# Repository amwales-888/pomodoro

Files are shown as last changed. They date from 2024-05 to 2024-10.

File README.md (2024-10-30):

# Pomodoro Timer

This simple project was requested by a client.

### Step 1. Hardware time preset

Produce a Pomodoro Timer where you can set the working time and rest time

The client proposed a set of jumper headers to configure timers along with a sketch of the hardware.

<table>
  <tr>
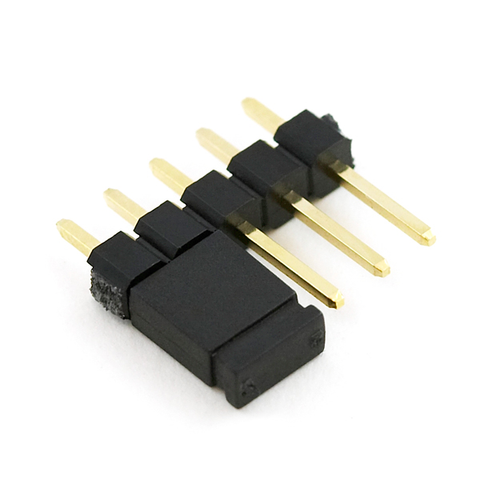
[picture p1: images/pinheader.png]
    <td> </td>
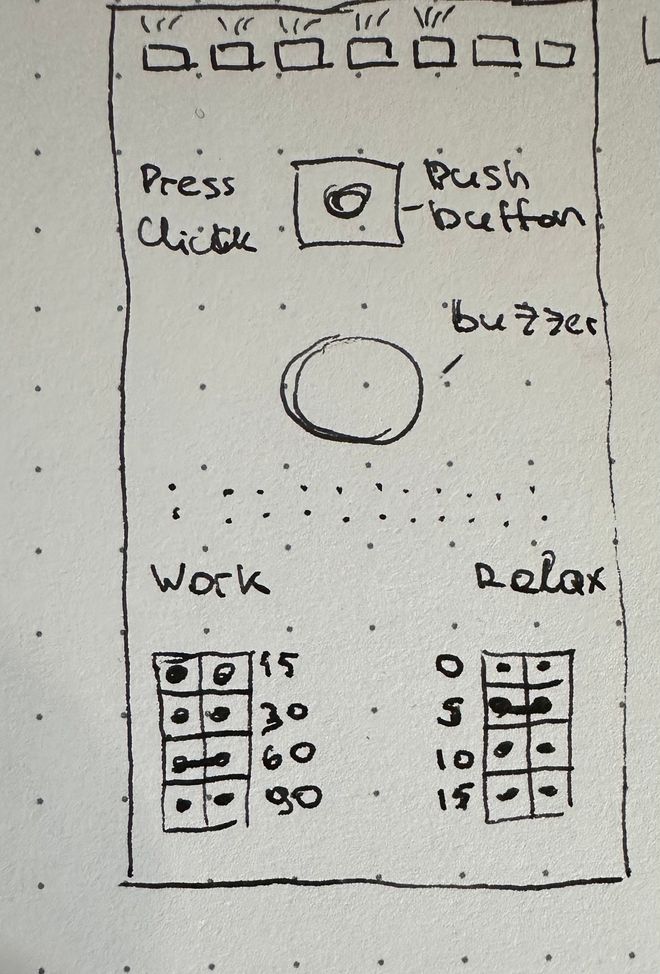
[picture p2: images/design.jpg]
    <td> </td>
  </tr>
</table>

Timers value are hardcoded 

Working time

- 15 minutes
- 30 minutes
- 60 minutes
- 90 minutes

Relax time

-  0 min
-  5 min
- 10 min
- 15 min

A row of LED are used to display the state of the timers.

### Step 2. Start timer

User clicks button to start timer

User hears sound from buzzer

LED progress bar turned on 

- Logic of the LED progress bar
    - Countdown progress bar
        - Ex: 30 minutes timer
        - 10 LEDs are on
        - the last one 10th is flashing
        - Every 3 minutes (time/amount of leds) 1 led turn off, after 3 minutes only 9 are on, the 9th is flashing

### Step 3. Timer is over

Once working timer is over:

- All progress bar LEDs flash
- Buzzer produce sound

Then User click button and Relax(Rest) timer began with the same logic

- Led progress bar has different color
- Once Rest timer finished - another melody is playing

To stop timer the User must hold the button pressed for 3 seconds. 

No pause function needed

### Power requirements

Ideally make it run from a tiny battery like CR2032 or 2-3 AAA Batteries.

### Enclosure requirements

No enclosure or enclosure built from PCB

### Size requirements

Less than 85 mm x 50mm 

## Proposal

 - Use a lowcost <a href="Firmware/pic16f15355/docs/PIC16F-LF-15354-55-Data-Sheet-DS40001853.pdf">pic16lf15355</a> SOIC 28 MCU which can be powered from 1.8v-5v, running from internal oscillator and able to idle at very low current.
 - Use 7 red/green bi-color, low power LEDs 
 - Use 2 AAA Batteries in series at 2v-3v to extend runtime and reduce end user cost over lithium CR2032 cell.
 - Use Microchip MPLAB-X, XC8 and Pickit5 for development.
 - 67mm x 40mm board area, battery holder mounted on the back.

<table>
  <tr>
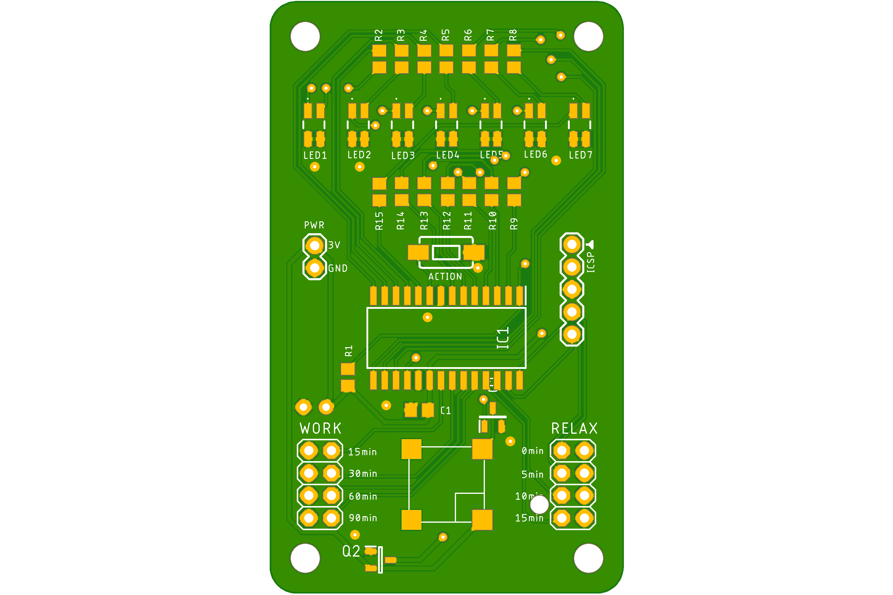
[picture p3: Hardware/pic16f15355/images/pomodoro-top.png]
    <td> </td>
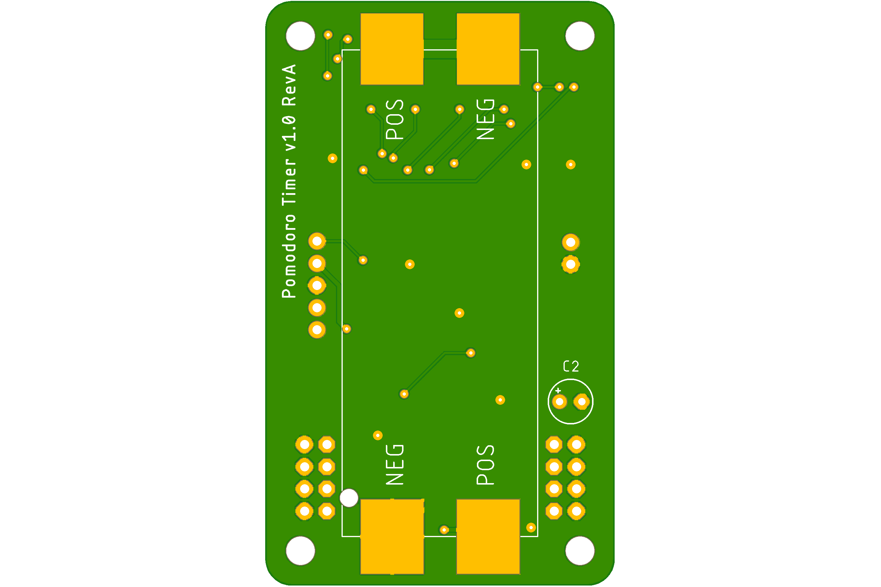
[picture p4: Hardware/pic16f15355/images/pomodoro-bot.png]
    <td> </td>
  </tr>
</table>

## Completed Project 

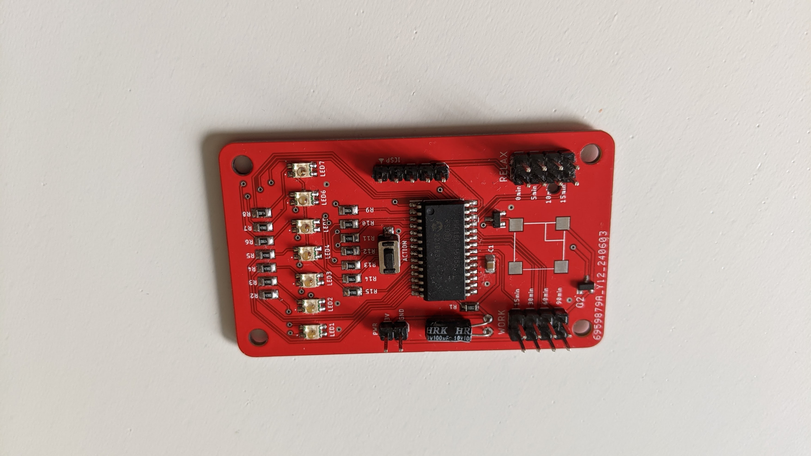
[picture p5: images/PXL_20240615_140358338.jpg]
Working, partially populated board 

## Project revision

I recently started investigating the py32 series of microcontrollers from puya, these are very low cost ( 12cents, you read that correctly ) arm-cortex-m0 processors running at 24MHz.
I ported the pomodoro firmware for the pic16 targeting the py32 controller and redsigned the board to support a tssop20 package. The new hardware is aimed at owering costs, along with the processor selection I opted for 14 leds in 0603 packages to reduce the cost. The complete BOM comes in at less than $1 and has feature parity with the original, supporting the same number of output and inputs as the original.

<table>
  <tr>
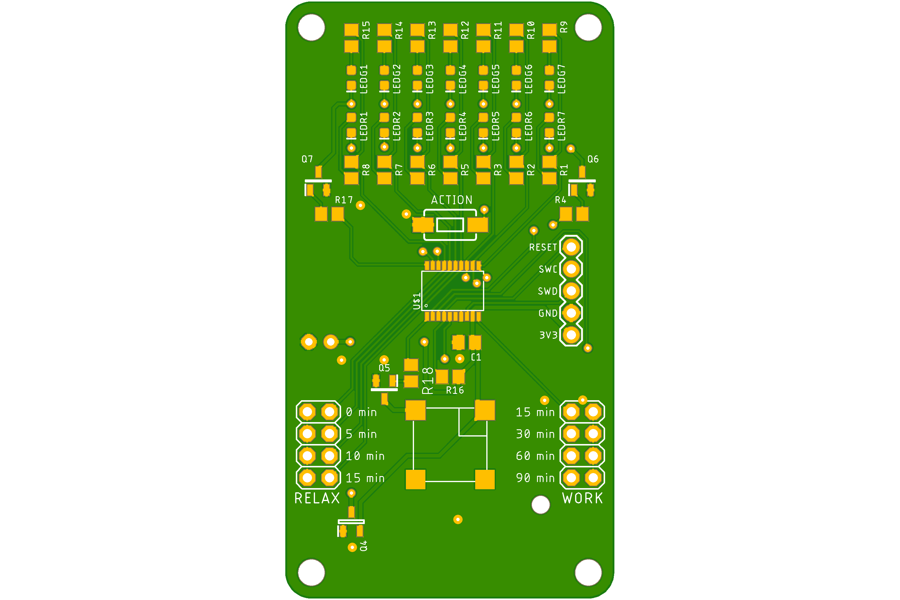
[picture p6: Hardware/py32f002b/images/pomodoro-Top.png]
    <td> </td>
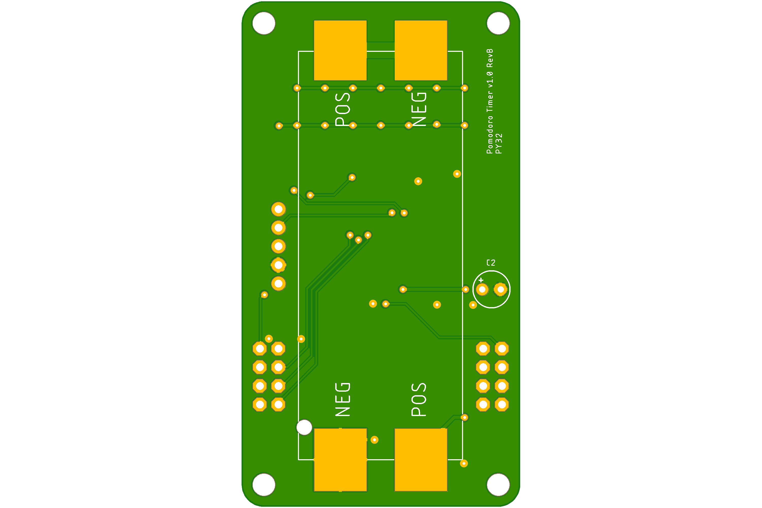
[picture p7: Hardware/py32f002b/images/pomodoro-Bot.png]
    <td> </td>
  </tr>
</table>

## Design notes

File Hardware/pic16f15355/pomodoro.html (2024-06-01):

Partlist exported from C:/Users/Angelo/Projects/pomodoro-pic16f15355/Hardware/pomodoro-pic16f15355/pomodoro.sch at 01/06/2024 14:47

Part | Value | Device | Package | Description | DESCRIPTION | HEIGHT | MANUFACTURER_NAME | MANUFACTURER_PART_NUMBER | MOUSER_PART_NUMBER | MOUSER_PRICE-STOCK | POPULARITY | PROD_ID | SF_SKU | SPICEPREFIX
ACTION | MOMENTARY-SWITCH-SPST-SMD-6.0X3.5MM | MOMENTARY-SWITCH-SPST-SMD-6.0X3.5MM | TACTILE_SWITCH_SMD_6.0X3.5MM | Momentary Switch (Pushbutton) - SPST | | | | | | | | SWCH-14278 | COM-08229
C1 | 0.1uf | C-EUC0805 | C0805 | CAPACITOR, European symbol | | | | | | | 88 | | | C
C2 | | CPOL-EUE2.5-5 | E2,5-5 | POLARIZED CAPACITOR, European symbol | | | | | | | 16 | | | C
IC1 | PIC16F15355T-I_SO | PIC16F15355T-I_SO | SOIC127P1030X265-28M | MCU 8-bit PIC RISC 14KB Flash 3.3V/5V 28-Pin SOIC W T/R | MCU 8-bit PIC RISC 14KB Flash 3.3V/5V 28-Pin SOIC W T/R | 2.65mm | Microchip | PIC16F15355T-I/SO | 579-PIC16F15355TI/SO | https://www.mouser.co.uk/ProductDetail/Microchip-Technology/PIC16F15355T-I-SO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
ICSP | | CONN_05 | 1X05 | Multi connection point. Often used as Generic Header-pin footprint for 0.1 inch spaced/style header connections
LED1 | APBD3224LSURKCGKC | APBD3224LSURKCGKC | APBD3224LSURKCGKC | Standard LEDs - SMD 3.2x2.4MM LOW CU RED/GREEN SMD | Standard LEDs - SMD 3.2x2.4MM LOW CU RED/GREEN SMD | 2.4mm | Kingbright | APBD3224LSURKCGKC | 604-APBD3224LSURKCGK | https://www.mouser.co.uk/ProductDetail/Kingbright/APBD3224LSURKCGKC?qs=ZqXcJfGlKsjckDFm0SXANw%3D%3D
LED2 | APBD3224LSURKCGKC | APBD3224LSURKCGKC | APBD3224LSURKCGKC | Standard LEDs - SMD 3.2x2.4MM LOW CU RED/GREEN SMD | Standard LEDs - SMD 3.2x2.4MM LOW CU RED/GREEN SMD | 2.4mm | Kingbright | APBD3224LSURKCGKC | 604-APBD3224LSURKCGK | https://www.mouser.co.uk/ProductDetail/Kingbright/APBD3224LSURKCGKC?qs=ZqXcJfGlKsjckDFm0SXANw%3D%3D
LED3 | APBD3224LSURKCGKC | APBD3224LSURKCGKC | APBD3224LSURKCGKC | Standard LEDs - SMD 3.2x2.4MM LOW CU RED/GREEN SMD | Standard LEDs - SMD 3.2x2.4MM LOW CU RED/GREEN SMD | 2.4mm | Kingbright | APBD3224LSURKCGKC | 604-APBD3224LSURKCGK | https://www.mouser.co.uk/ProductDetail/Kingbright/APBD3224LSURKCGKC?qs=ZqXcJfGlKsjckDFm0SXANw%3D%3D
LED4 | APBD3224LSURKCGKC | APBD3224LSURKCGKC | APBD3224LSURKCGKC | Standard LEDs - SMD 3.2x2.4MM LOW CU RED/GREEN SMD | Standard LEDs - SMD 3.2x2.4MM LOW CU RED/GREEN SMD | 2.4mm | Kingbright | APBD3224LSURKCGKC | 604-APBD3224LSURKCGK | https://www.mouser.co.uk/ProductDetail/Kingbright/APBD3224LSURKCGKC?qs=ZqXcJfGlKsjckDFm0SXANw%3D%3D
LED5 | APBD3224LSURKCGKC | APBD3224LSURKCGKC | APBD3224LSURKCGKC | Standard LEDs - SMD 3.2x2.4MM LOW CU RED/GREEN SMD | Standard LEDs - SMD 3.2x2.4MM LOW CU RED/GREEN SMD | 2.4mm | Kingbright | APBD3224LSURKCGKC | 604-APBD3224LSURKCGK | https://www.mouser.co.uk/ProductDetail/Kingbright/APBD3224LSURKCGKC?qs=ZqXcJfGlKsjckDFm0SXANw%3D%3D
LED6 | APBD3224LSURKCGKC | APBD3224LSURKCGKC | APBD3224LSURKCGKC | Standard LEDs - SMD 3.2x2.4MM LOW CU RED/GREEN SMD | Standard LEDs - SMD 3.2x2.4MM LOW CU RED/GREEN SMD | 2.4mm | Kingbright | APBD3224LSURKCGKC | 604-APBD3224LSURKCGK | https://www.mouser.co.uk/ProductDetail/Kingbright/APBD3224LSURKCGKC?qs=ZqXcJfGlKsjckDFm0SXANw%3D%3D
LED7 | APBD3224LSURKCGKC | APBD3224LSURKCGKC | APBD3224LSURKCGKC | Standard LEDs - SMD 3.2x2.4MM LOW CU RED/GREEN SMD | Standard LEDs - SMD 3.2x2.4MM LOW CU RED/GREEN SMD | 2.4mm | Kingbright | APBD3224LSURKCGKC | 604-APBD3224LSURKCGK | https://www.mouser.co.uk/ProductDetail/Kingbright/APBD3224LSURKCGKC?qs=ZqXcJfGlKsjckDFm0SXANw%3D%3D
PWR | | CONN_02 | 1X02 | Multi connection point. Often used as Generic Header-pin footprint for 0.1 inch spaced/style header connections
Q1 | IRLML2502TRPBF | IRLML2502TRPBF | SOT95P237X112-3N | IRLML2502TRPBF N-Channel MOSFET, 4.2 A, 20 V IRLML2502, 3-Pin SOT-23 Infineon | IRLML2502TRPBF N-Channel MOSFET, 4.2 A, 20 V IRLML2502, 3-Pin SOT-23 Infineon | 1.12mm | Infineon | IRLML2502TRPBF | 942-IRLML2502TRPBF | https://www.mouser.co.uk/ProductDetail/Infineon-Technologies/IRLML2502TRPBF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
Q2 | DMG2305UX-7 | DMG2305UX-7 | SOT96P240X115-3N | MOSFET P-Ch 20V 5A Enhancement SOT23 Diodes Inc DMG2305UX-7 P-channel MOSFET Transistor, -3.3 A, -20 V, 3-Pin SOT-23 | MOSFET P-Ch 20V 5A Enhancement SOT23 Diodes Inc DMG2305UX-7 P-channel MOSFET Transistor, -3.3 A, -20 V, 3-Pin SOT-23 | 1.15mm | Diodes Incorporated | DMG2305UX-7 | 621-DMG2305UX-7 | https://www.mouser.co.uk/ProductDetail/Diodes-Incorporated/DMG2305UX-7?qs=L1DZKBg7t5F%2FNBHrjfxC%252Bg%3D%3D
R1 | 10K | R-EU_R0805 | R0805 | RESISTOR, European symbol | | | | | | | 86 | | | R
R2 | 330R | R-EU_R0805 | R0805 | RESISTOR, European symbol | | | | | | | 86 | | | R
R3 | 330R | R-EU_R0805 | R0805 | RESISTOR, European symbol | | | | | | | 86 | | | R
R4 | 330R | R-EU_R0805 | R0805 | RESISTOR, European symbol | | | | | | | 86 | | | R
R5 | 330R | R-EU_R0805 | R0805 | RESISTOR, European symbol | | | | | | | 86 | | | R
R6 | 330R | R-EU_R0805 | R0805 | RESISTOR, European symbol | | | | | | | 86 | | | R
R7 | 330R | R-EU_R0805 | R0805 | RESISTOR, European symbol | | | | | | | 86 | | | R
R8 | 330R | R-EU_R0805 | R0805 | RESISTOR, European symbol | | | | | | | 86 | | | R
R9 | 330R | R-EU_R0805 | R0805 | RESISTOR, European symbol | | | | | | | 86 | | | R
R10 | 330R | R-EU_R0805 | R0805 | RESISTOR, European symbol | | | | | | | 86 | | | R
R11 | 330R | R-EU_R0805 | R0805 | RESISTOR, European symbol | | | | | | | 86 | | | R
R12 | 330R | R-EU_R0805 | R0805 | RESISTOR, European symbol | | | | | | | 86 | | | R
R13 | 330R | R-EU_R0805 | R0805 | RESISTOR, European symbol | | | | | | | 86 | | | R
R14 | 330R | R-EU_R0805 | R0805 | RESISTOR, European symbol | | | | | | | 86 | | | R
R15 | 330R | R-EU_R0805 | R0805 | RESISTOR, European symbol | | | | | | | 86 | | | R
RELAX | | PINHD-2X4 | 2X04 | PIN HEADER | | | | | | | 47
U$1 | 2AAABATT | 2AAABATT | 2AAABATTSER
U$2 | BUZZER8X8 | BUZZER8X8 | BUZZER8X8
WORK | | PINHD-2X4 | 2X04 | PIN HEADER | | | | | | | 47

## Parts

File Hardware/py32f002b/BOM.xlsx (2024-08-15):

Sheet: Sheet1
LCSC Part Number | Manufacture Part Number | Manufacturer | Customer NO. | Package | Description |  | Unit Price($) | #Required | Price
C7496820 | F.0603.00139/P2-0603R1TS2-06T-002 | TUOZHAN |  | 603 | 5mA -40â„ƒ~+85â„ƒ Red 120Â° 0603 LED Indication - Discrete ROHS |  | 0.0031 | 7 | 0.0217
C7496818 | F.0603.00025/P2-0603G1TS2-06T-002 | TUOZHAN |  | 603 | 5mA 230mcd 520nm~525nm -40â„ƒ~+85â„ƒ Emerald 120Â° 2.6V~2.9V 0603 LED Indication - Discrete ROHS |  | 0.0029 | 7 | 0.0203
C94599 | MLT-8530 | Jiangsu Huaneng Elec |  | SMD,8.5x8.5mm | 80dB Externally Driven Magnetic 2.7kHz SMD,8.5x8.5mm Buzzers ROHS |  | 0.1924 | 1 | 0.1924
C22438998 | PY32F002BF15P6TR | PUYAï¼‰ |  | TSSOP-20 | TSSOP-20 Microcontrollers (MCU/MPU/SOC) ROHS |  | 0.1369 | 1 | 0.1369
C5290190 | BH-AAA-B1AJ015-60 | MYOUNG |  | - | Battery case No 7 - Button And Strip Battery Connector ROHS |  | 0.2714 | 1 | 0.2714
C429959 | 12251140CNG0S115001 | JILN |  | Plugin,P=2.54mm | 3A Straight Square Pins 2.5mm 40P 6mm -40â„ƒ~+105â„ƒ 3mm 2.54mm Plugin Black Brass 1x40P Plugin,P=2.54mm Pin Headers ROHS |  | 0.1016 | 1 | 0.1016
C17471 | 0805W8F1500T5E | UNI-ROYAL(Uniroyal Elec) |  | 805 | 125mW Thick Film Resistors 150V Â±100ppm/â„ƒ Â±1% 150Î© 0805 Chip Resistor - Surface Mount ROHS |  | 0.0017 | 14 | 0.0238
C150470 | DMG2305UX-7 | Diodes Incorporated |  | SOT-23 | 20V 4.2A 52mÎ©@4.5V,4.2A 1.4W 900mV@250uA 1PCSPChannel SOT-23 MOSFETs ROHS |  | 0.0466 | 1 | 0.0466
C337069 | SL3906 | Slkor(SLKORMICRO Elec.) |  | SOT-23 | 40V 225mW 100@10mA,1V 200mA PNP SOT-23 Bipolar (BJT) ROHS |  | 0.0075 | 3 | 0.0225
C66501 | CL10B104KO8NNNC | Samsung Electro-Mechanics |  | 603 | 16V 100nF X7R Â±10% 0603 Multilayer Ceramic Capacitors MLCC - SMD/SMT ROHS |  | 0.0026 | 1 | 0.0026
C84376 | RC0805FR-0710KL | YAGEO |  | 805 | 125mW Thick Film Resistors 150V Â±100ppm/â„ƒ Â±1% 10kÎ© 0805 Chip Resistor - Surface Mount ROHS |  | 0.0019 | 1 | 0.0019
C7499926 | CD110107M1A0407VFL | HRK |  | Plugin,D4xL7mm | 100uF 10V Plugin,D4xL7mm Aluminum Electrolytic Capacitors - Leaded ROHS |  | 0.0056 | 1 | 0.0056
 |  |  |  |  |  |  |  |  | 0.8473
ACTION | MOMENTARY-SWITCH-SPST-SMD-6.0X3.5MM | MOMENTARY-SWITCH-SPST-SMD-6.0X3.5MM
C1 | 100nf | C-EUC0805 |  | CAPACITOR, European symbol
C2 | 100uf | CPOL-EUE2.5-5 |  | POLARIZED CAPACITOR, European symbol
J1 |  | CONN_05 |  | PIN HEADER
LEDG1 | 20ma | LEDSML0805 |  | LED |  | 0.0031
LEDG2 | 20ma | LEDSML0805 |  | LED |  | 0.0031
LEDG3 | 20ma | LEDSML0805 |  | LED |  | 0.0031
LEDG4 | 20ma | LEDSML0805 |  | LED |  | 0.0031
LEDG5 | 20ma | LEDSML0805 |  | LED |  | 0.0031
LEDG6 | 20ma | LEDSML0805 |  | LED |  | 0.0031
LEDG7 | 20ma | LEDSML0805 |  | LED |  | 0.0031
LEDR1 | 20ma | LEDSML0805 |  | LED |  | 0.0031
LEDR2 | 20ma | LEDSML0805 |  | LED |  | 0.0031
LEDR3 | 20ma | LEDSML0805 |  | LED |  | 0.0031
LEDR4 | 20ma | LEDSML0805 |  | LED |  | 0.0031
LEDR5 | 20ma | LEDSML0805 |  | LED |  | 0.0031
LEDR6 | 20ma | LEDSML0805 | C7496820 | LED |  | 0.0031
LEDR7 | 20ma | LEDSML0805 | C7496818 | LED |  | 0.0031
Q4 | DMG2305UX-7 | DMG2305UX-7 | C150470 | MOSFET P-Ch 20V 5A Enhancement SOT23 Diodes Inc DMG2305UX-7 P-channel MOSFET Transistor, -3.3 A, -20 V, 3-Pin SOT-23 |  | 0.0466
Q5 | MMBT3904LT3G | MMBT3904LT3G | C337069 | Transistor NPN 40V 200mA SOT-23 ON Semi MMBT3904LT3G NPN Bipolar Transistor, 900 mA 40 V, 3-Pin SOT-23
Q6 | MMBT3904LT3G | MMBT3904LT3G | C337069 | Transistor NPN 40V 200mA SOT-23 ON Semi MMBT3904LT3G NPN Bipolar Transistor, 900 mA 40 V, 3-Pin SOT-23
Q7 | MMBT3904LT3G | MMBT3904LT3G | C337069 | Transistor NPN 40V 200mA SOT-23 ON Semi MMBT3904LT3G NPN Bipolar Transistor, 900 mA 40 V, 3-Pin SOT-23
R1 | 100R | R-EU_R0805 |  | RESISTOR, European symbol
R2 | 100R | R-EU_R0805 |  | RESISTOR, European symbol
R3 | 100R | R-EU_R0805 |  | RESISTOR, European symbol
R4 | 10k | R-EU_R0805 |  | RESISTOR, European symbol
R5 | 100R | R-EU_R0805 |  | RESISTOR, European symbol
R6 | 100R | R-EU_R0805 |  | RESISTOR, European symbol
R7 | 100R | R-EU_R0805 |  | RESISTOR, European symbol
R8 | 100R | R-EU_R0805 |  | RESISTOR, European symbol
R9 | 100R | R-EU_R0805 |  | RESISTOR, European symbol
R10 | 100R | R-EU_R0805 |  | RESISTOR, European symbol
R11 | 100R | R-EU_R0805 |  | RESISTOR, European symbol
R12 | 100R | R-EU_R0805 |  | RESISTOR, European symbol
R13 | 100R | R-EU_R0805 |  | RESISTOR, European symbol
R14 | 100R | R-EU_R0805 |  | RESISTOR, European symbol
R15 | 100R | R-EU_R0805 |  | RESISTOR, European symbol
R16 | 100R | R-EU_R0805 |  | RESISTOR, European symbol
R17 | 10K | R-EU_R0805 |  | RESISTOR, European symbol
R18 | 10k | R-EU_R0805 |  | RESISTOR, European symbol
RELAX | 3A Straight Square Pins 2.5mm | PINHD-2X4 | C429959 | PIN HEADER
U$1 | PY32F002BF15P6TU | PY32F002BF15P6TU | C22438998
U$2 | BUZZER8X8 | BUZZER8X8 | C94599
U$3 | 2AAABATT | 2AAABATT | C5290190
WORK | 3A Straight Square Pins 2.5mm | PINHD-2X4 | C429959 | PIN HEADER

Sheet: Sheet2
Part | Value | Device | Package | Description | DESCRIPTION | HEIGHT | MANUFACTURER_NAME | MANUFACTURER_PART_NUMBER | MOUSER_PART_NUMBER | MOUSER_PRICE-STOCK | POPULARITY | PROD_ID | SF_SKU | SPICEPREFIX
ACTION | MOMENTARY-SWITCH-SPST-SMD-6.0X3.5MM | MOMENTARY-SWITCH-SPST-SMD-6.0X3.5MM | TACTILE_SWITCH_SMD_6.0X3.5MM | Momentary Switch (Pushbutton) - SPST |  |  |  |  |  |  |  | SWCH-14278 | COM-08229
C1 |  | C-EUC0805 | C0805 | CAPACITOR, European symbol |  |  |  |  |  |  | 88 |  |  | C
C2 |  | CPOL-EUE2.5-5 | E2,5-5 | POLARIZED CAPACITOR, European symbol |  |  |  |  |  |  | 16 |  |  | C
J1 |  | CONN_05 | 1X05 | Multi connection point. Often used as Generic Header-pin footprint for 0.1 inch spaced/style header connections
LEDG1 | 20ma | LEDSML0805 | SML0805 | LED |  |  |  |  |  |  | 17
LEDG2 | 20ma | LEDSML0805 | SML0805 | LED |  |  |  |  |  |  | 17
LEDG3 | 20ma | LEDSML0805 | SML0805 | LED |  |  |  |  |  |  | 17
LEDG4 | 20ma | LEDSML0805 | SML0805 | LED |  |  |  |  |  |  | 17
LEDG5 | 20ma | LEDSML0805 | SML0805 | LED |  |  |  |  |  |  | 17
LEDG6 | 20ma | LEDSML0805 | SML0805 | LED |  |  |  |  |  |  | 17
LEDG7 | 20ma | LEDSML0805 | SML0805 | LED |  |  |  |  |  |  | 17
LEDR1 | 20ma | LEDSML0805 | SML0805 | LED |  |  |  |  |  |  | 17
LEDR2 | 20ma | LEDSML0805 | SML0805 | LED |  |  |  |  |  |  | 17
LEDR3 | 20ma | LEDSML0805 | SML0805 | LED |  |  |  |  |  |  | 17
LEDR4 | 20ma | LEDSML0805 | SML0805 | LED |  |  |  |  |  |  | 17
LEDR5 | 20ma | LEDSML0805 | SML0805 | LED |  |  |  |  |  |  | 17
LEDR6 | 20ma | LEDSML0805 | SML0805 | LED |  |  |  |  |  |  | 17
LEDR7 | 20ma | LEDSML0805 | SML0805 | LED |  |  |  |  |  |  | 17
Q4 | DMG2305UX-7 | DMG2305UX-7 | SOT96P240X115-3N | MOSFET P-Ch 20V 5A Enhancement SOT23 Diodes Inc DMG2305UX-7 P-channel MOSFET Transistor, -3.3 A, -20 V, 3-Pin SOT-23 | MOSFET P-Ch 20V 5A Enhancement SOT23 Diodes Inc DMG2305UX-7 P-channel MOSFET Transistor, -3.3 A, -20 V, 3-Pin SOT-23 | 1.15mm | Diodes Incorporated | DMG2305UX-7 | 621-DMG2305UX-7 | https://www.mouser.co.uk/ProductDetail/Diodes-Incorporated/DMG2305UX-7?qs=L1DZKBg7t5F%2FNBHrjfxC%252Bg%3D%3D
Q5 | MMBT3904LT3G | MMBT3904LT3G | SOT96P237X111-3N | Transistor NPN 40V 200mA SOT-23 ON Semi MMBT3904LT3G NPN Bipolar Transistor, 900 mA 40 V, 3-Pin SOT-23 | Transistor NPN 40V 200mA SOT-23 ON Semi MMBT3904LT3G NPN Bipolar Transistor, 900 mA 40 V, 3-Pin SOT-23 | 1.11mm | onsemi | MMBT3904LT3G | 863-MMBT3904LT3G | https://www.mouser.co.uk/ProductDetail/onsemi/MMBT3904LT3G?qs=HVbQlW5zcXUpjKhCMxE5QQ%3D%3D
Q6 | MMBT3904LT3G | MMBT3904LT3G | SOT96P237X111-3N | Transistor NPN 40V 200mA SOT-23 ON Semi MMBT3904LT3G NPN Bipolar Transistor, 900 mA 40 V, 3-Pin SOT-23 | Transistor NPN 40V 200mA SOT-23 ON Semi MMBT3904LT3G NPN Bipolar Transistor, 900 mA 40 V, 3-Pin SOT-23 | 1.11mm | onsemi | MMBT3904LT3G | 863-MMBT3904LT3G | https://www.mouser.co.uk/ProductDetail/onsemi/MMBT3904LT3G?qs=HVbQlW5zcXUpjKhCMxE5QQ%3D%3D
Q7 | MMBT3904LT3G | MMBT3904LT3G | SOT96P237X111-3N | Transistor NPN 40V 200mA SOT-23 ON Semi MMBT3904LT3G NPN Bipolar Transistor, 900 mA 40 V, 3-Pin SOT-23 | Transistor NPN 40V 200mA SOT-23 ON Semi MMBT3904LT3G NPN Bipolar Transistor, 900 mA 40 V, 3-Pin SOT-23 | 1.11mm | onsemi | MMBT3904LT3G | 863-MMBT3904LT3G | https://www.mouser.co.uk/ProductDetail/onsemi/MMBT3904LT3G?qs=HVbQlW5zcXUpjKhCMxE5QQ%3D%3D
R1 | 100R | R-EU_R0805 | R0805 | RESISTOR, European symbol |  |  |  |  |  |  | 86 |  |  | R
R2 | 100R | R-EU_R0805 | R0805 | RESISTOR, European symbol |  |  |  |  |  |  | 86 |  |  | R
R3 | 100R | R-EU_R0805 | R0805 | RESISTOR, European symbol |  |  |  |  |  |  | 86 |  |  | R
R4 | 10k | R-EU_R0805 | R0805 | RESISTOR, European symbol |  |  |  |  |  |  | 86 |  |  | R
R5 | 100R | R-EU_R0805 | R0805 | RESISTOR, European symbol |  |  |  |  |  |  | 86 |  |  | R
R6 | 100R | R-EU_R0805 | R0805 | RESISTOR, European symbol |  |  |  |  |  |  | 86 |  |  | R
R7 | 100R | R-EU_R0805 | R0805 | RESISTOR, European symbol |  |  |  |  |  |  | 86 |  |  | R
R8 | 100R | R-EU_R0805 | R0805 | RESISTOR, European symbol |  |  |  |  |  |  | 86 |  |  | R
R9 | 100R | R-EU_R0805 | R0805 | RESISTOR, European symbol |  |  |  |  |  |  | 86 |  |  | R
R10 | 100R | R-EU_R0805 | R0805 | RESISTOR, European symbol |  |  |  |  |  |  | 86 |  |  | R
R11 | 100R | R-EU_R0805 | R0805 | RESISTOR, European symbol |  |  |  |  |  |  | 86 |  |  | R
R12 | 100R | R-EU_R0805 | R0805 | RESISTOR, European symbol |  |  |  |  |  |  | 86 |  |  | R
R13 | 100R | R-EU_R0805 | R0805 | RESISTOR, European symbol |  |  |  |  |  |  | 86 |  |  | R
R14 | 100R | R-EU_R0805 | R0805 | RESISTOR, European symbol |  |  |  |  |  |  | 86 |  |  | R
R15 | 100R | R-EU_R0805 | R0805 | RESISTOR, European symbol |  |  |  |  |  |  | 86 |  |  | R
R16 | 100R | R-EU_R0805 | R0805 | RESISTOR, European symbol |  |  |  |  |  |  | 86 |  |  | R
R17 | 10K | R-EU_R0805 | R0805 | RESISTOR, European symbol |  |  |  |  |  |  | 86 |  |  | R
R18 | 10k | R-EU_R0805 | R0805 | RESISTOR, European symbol |  |  |  |  |  |  | 86 |  |  | R
RELAX |  | PINHD-2X4 | 2X04 | PIN HEADER |  |  |  |  |  |  | 47
U$1 | PY32F002BF15P6TU | PY32F002BF15P6TU | TSSOP20
U$2 | BUZZER8X8 | BUZZER8X8 | BUZZER8X8
U$3 | 2AAABATT | 2AAABATT | 2AAABATTSER
WORK |  | PINHD-2X4 | 2X04 | PIN HEADER |  |  |  |  |  |  | 47

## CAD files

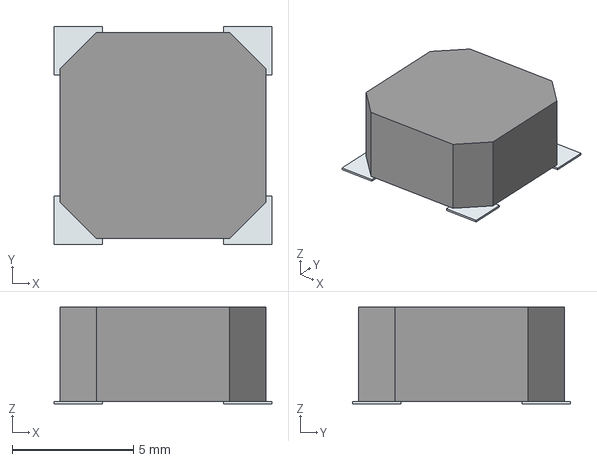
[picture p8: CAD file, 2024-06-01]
Hardware/pic16f15355/3dmodels/CMI-8536-82-SMT-TR.stp
9.00 x 9.00 x 4.00 mm
Pins

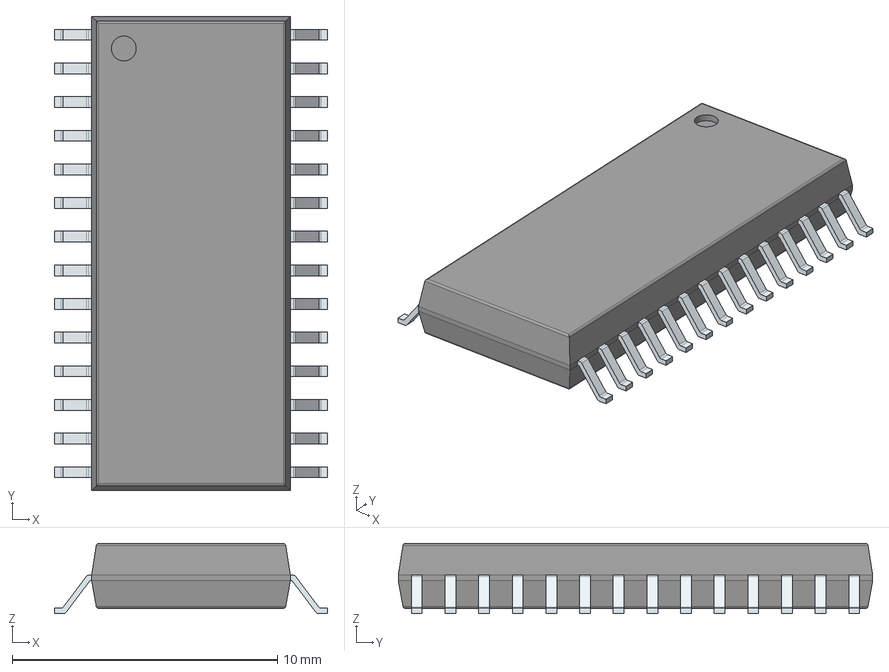
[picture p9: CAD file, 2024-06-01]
Hardware/pic16f15355/3dmodels/PIC16F15355T-I_SO.stp
10.3 x 17.9 x 2.65 mm
PinsArrayLR

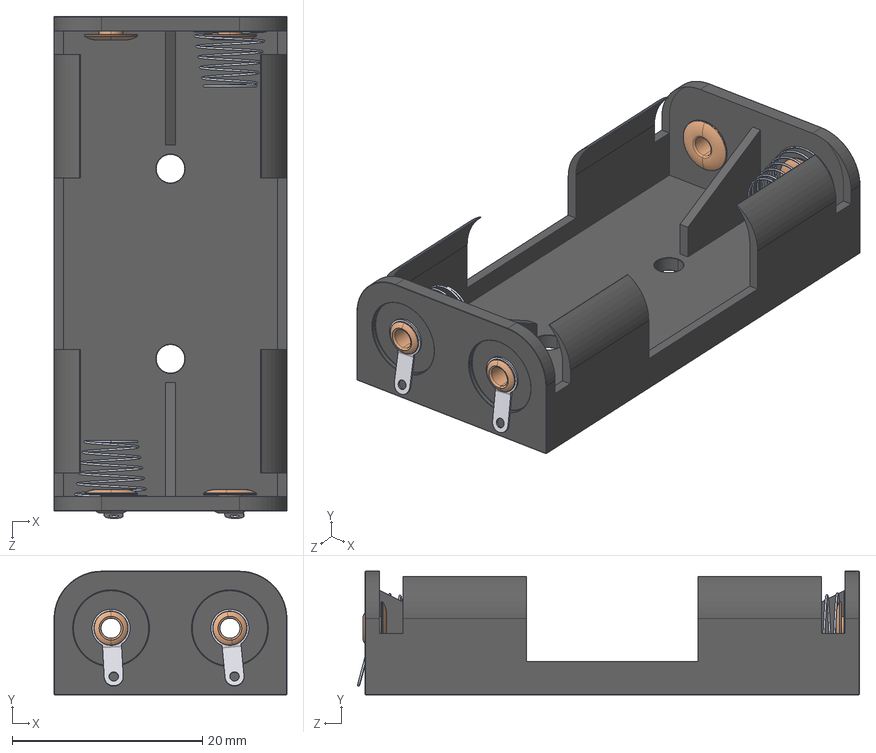
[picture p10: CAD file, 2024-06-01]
Hardware/pic16f15355/3dmodels/koszyk 2xAAA_214.STEP
24.5 x 13.0 x 52.8 mm
battery holder 2 x AAA
wtyczka x 2
wstawka x 4
sprezyna x 2

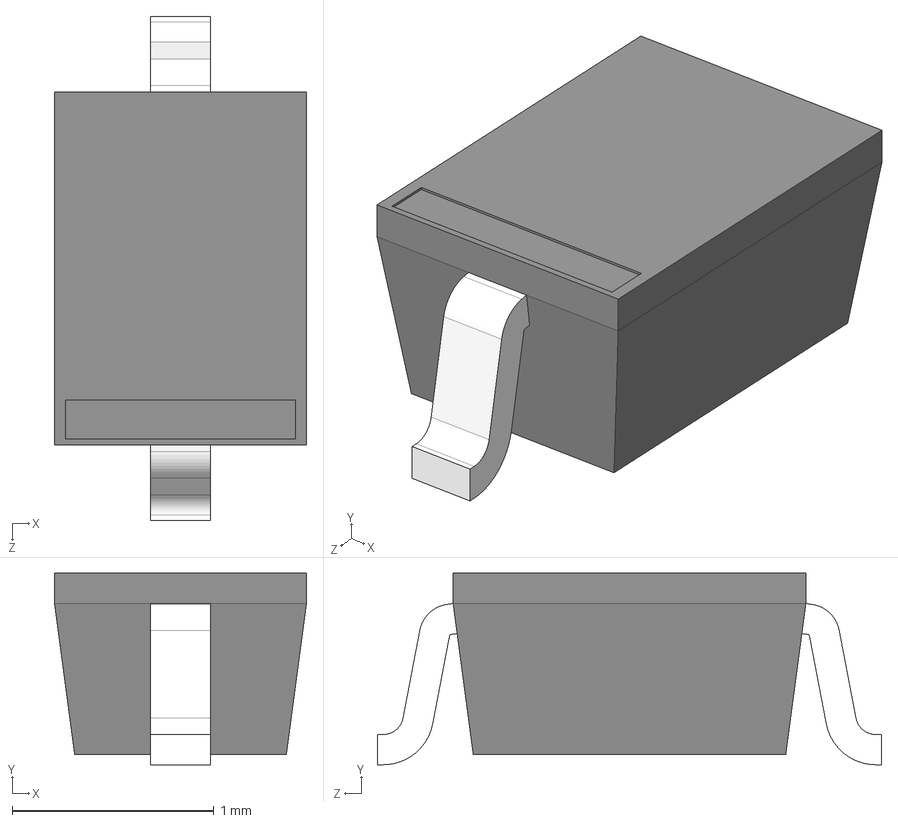
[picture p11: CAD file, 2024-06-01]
Hardware/pic16f15355/3dmodels/CUS10S30,H3F.stp
1.25 x 0.95 x 2.50 mm

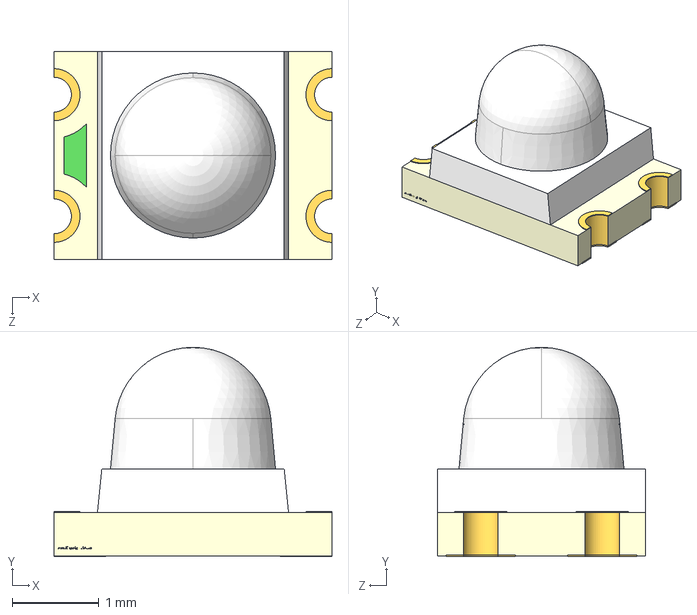
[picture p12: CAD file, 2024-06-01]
Hardware/pic16f15355/3dmodels/APBD3224LSURKCGKC.stp
3.20 x 2.41 x 2.40 mm

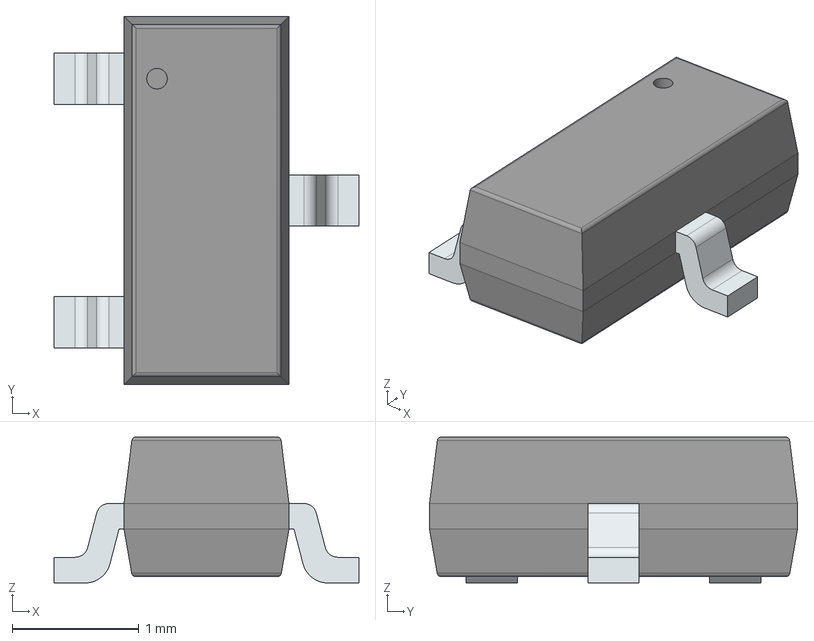
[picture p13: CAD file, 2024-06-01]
Hardware/pic16f15355/3dmodels/DMG2305UX-7.stp
2.40 x 2.90 x 1.15 mm
PinsArrayL
FilletPinR

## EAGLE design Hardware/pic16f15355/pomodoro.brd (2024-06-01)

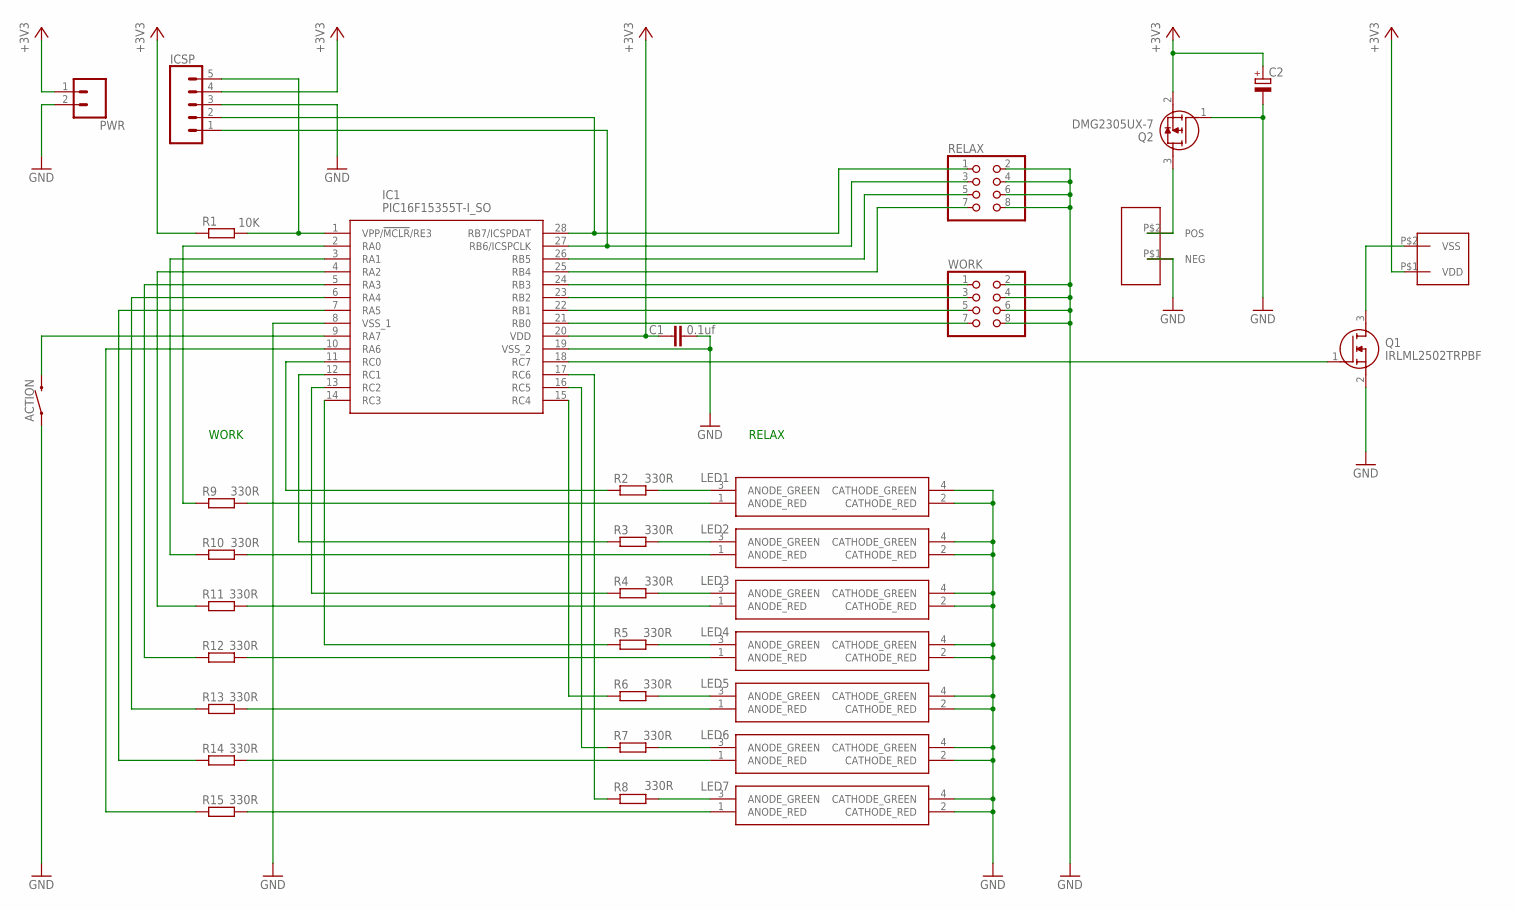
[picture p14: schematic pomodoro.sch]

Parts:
ACTION: MOMENTARY-SWITCH-SPST-SMD-6.0X3.5MM; TACTILE_SWITCH_SMD_6.0X3.5MM
C1: 0.1uf; C0805
C2: CPOL-EUE2.5-5; E2,5-5
IC1: PIC16F15355T-I_SO; SOIC127P1030X265-28M
ICSP: CONN_05; 1X05
LED1, LED2, LED3, LED4, LED5, LED6, LED7: APBD3224LSURKCGKC
PWR: CONN_02; 1X02
Q1: IRLML2502TRPBF; SOT95P237X112-3N
Q2: DMG2305UX-7; SOT96P240X115-3N
R1: 10K; R0805
R2, R3, R4, R5, R6, R7, R8, R9, R10, R11, R12, R13, R14, R15: 330R; R0805
RELAX: PINHD-2X4; 2X04
U$1: 2AAABATT; 2AAABATTSER
U$2: BUZZER8X8
WORK: PINHD-2X4; 2X04

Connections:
+3V3: C1.1, C2.+, IC1.20 (VDD), ICSP.4, PWR.1, Q2.2 (S), R1.1, U$2.P$1 (VDD)
GND: ACTION.1, C1.2, C2.-, IC1.8 (VSS_1), IC1.19 (VSS_2), ICSP.3, LED1.2 (CATHODE_RED), LED1.4 (CATHODE_GREEN), LED2.2 (CATHODE_RED), LED2.4 (CATHODE_GREEN), LED3.2 (CATHODE_RED), LED3.4 (CATHODE_GREEN), LED4.2 (CATHODE_RED), LED4.4 (CATHODE_GREEN), LED5.2 (CATHODE_RED), LED5.4 (CATHODE_GREEN), LED6.2 (CATHODE_RED), LED6.4 (CATHODE_GREEN), LED7.2 (CATHODE_RED), LED7.4 (CATHODE_GREEN), PWR.2, Q1.2 (S), Q2.1 (G), RELAX.2, RELAX.4, RELAX.6, RELAX.8, U$1.P$1 (NEG), WORK.2, WORK.4, WORK.6, WORK.8
unnamed: IC1.1 (VPP/!MCLR!/RE3), ICSP.5, R1.2
unnamed: LED1.1 (ANODE_RED), R9.2
unnamed: LED2.1 (ANODE_RED), R10.2
unnamed: IC1.28 (RB7/ICSPDAT), ICSP.2, RELAX.1
unnamed: IC1.27 (RB6/ICSPCLK), ICSP.1, RELAX.3
unnamed: LED3.1 (ANODE_RED), R11.2
unnamed: LED4.1 (ANODE_RED), R12.2
unnamed: LED5.1 (ANODE_RED), R13.2
unnamed: LED6.1 (ANODE_RED), R14.2
unnamed: LED7.1 (ANODE_RED), R15.2
unnamed: LED1.3 (ANODE_GREEN), R2.2
unnamed: LED2.3 (ANODE_GREEN), R3.2
unnamed: LED3.3 (ANODE_GREEN), R4.2
unnamed: LED4.3 (ANODE_GREEN), R5.2
unnamed: LED5.3 (ANODE_GREEN), R6.2
unnamed: LED6.3 (ANODE_GREEN), R7.2
unnamed: LED7.3 (ANODE_GREEN), R8.2
unnamed: ACTION.2, IC1.9 (RA7)
unnamed: IC1.11 (RC0), R2.1
unnamed: IC1.12 (RC1), R3.1
unnamed: IC1.13 (RC2), R4.1
unnamed: IC1.14 (RC3), R5.1
unnamed: IC1.15 (RC4), R6.1
unnamed: IC1.16 (RC5), R7.1
unnamed: IC1.17 (RC6), R8.1
unnamed: IC1.18 (RC7), Q1.1 (G)
unnamed: IC1.21 (RB0), WORK.7
unnamed: IC1.22 (RB1), WORK.5
unnamed: IC1.23 (RB2), WORK.3
unnamed: IC1.24 (RB3), WORK.1
unnamed: IC1.25 (RB4), RELAX.7
unnamed: IC1.26 (RB5), RELAX.5
unnamed: IC1.2 (RA0), R9.1
unnamed: IC1.3 (RA1), R10.1
unnamed: IC1.4 (RA2), R11.1
unnamed: IC1.5 (RA3), R12.1
unnamed: IC1.6 (RA4), R13.1
unnamed: IC1.7 (RA5), R14.1
unnamed: IC1.10 (RA6), R15.1
unnamed: Q1.3 (D), U$2.P$2 (VSS)
unnamed: Q2.3 (D), U$1.P$2 (POS)

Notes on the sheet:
WORK
RELAX

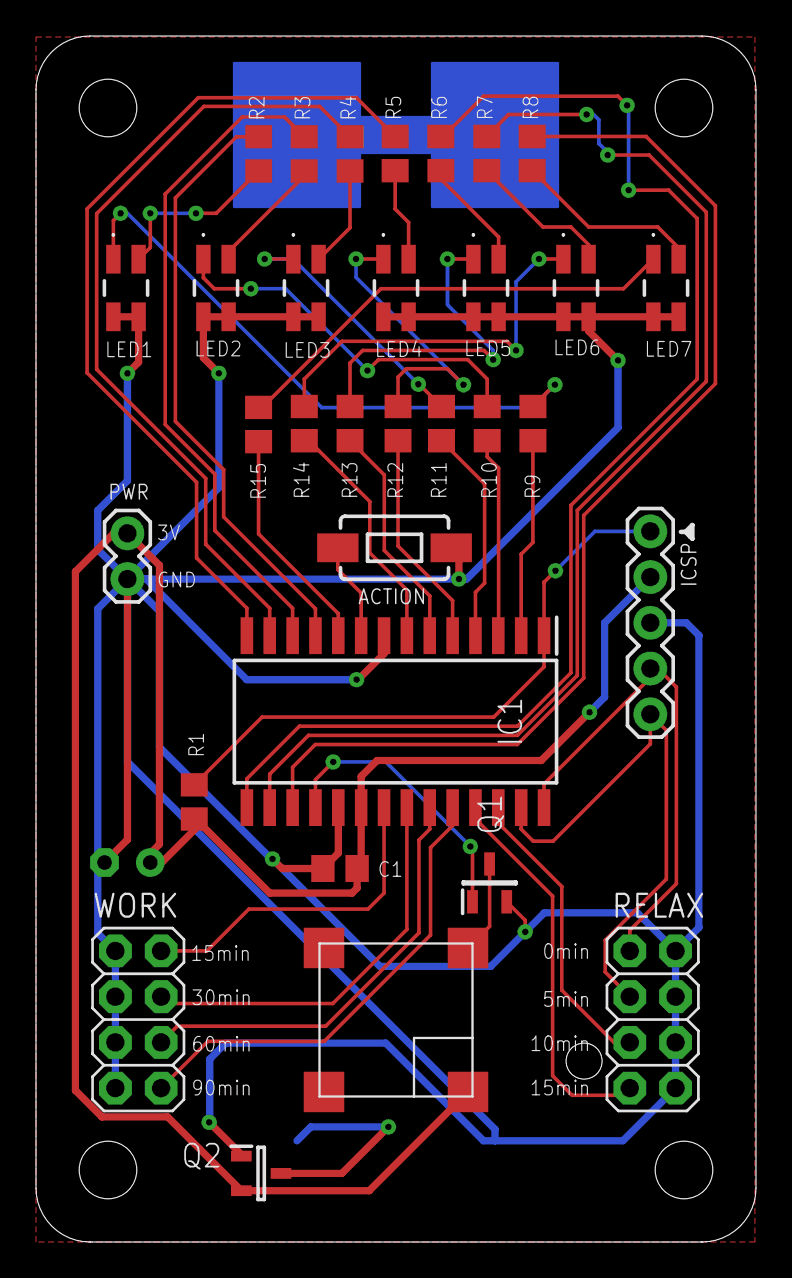
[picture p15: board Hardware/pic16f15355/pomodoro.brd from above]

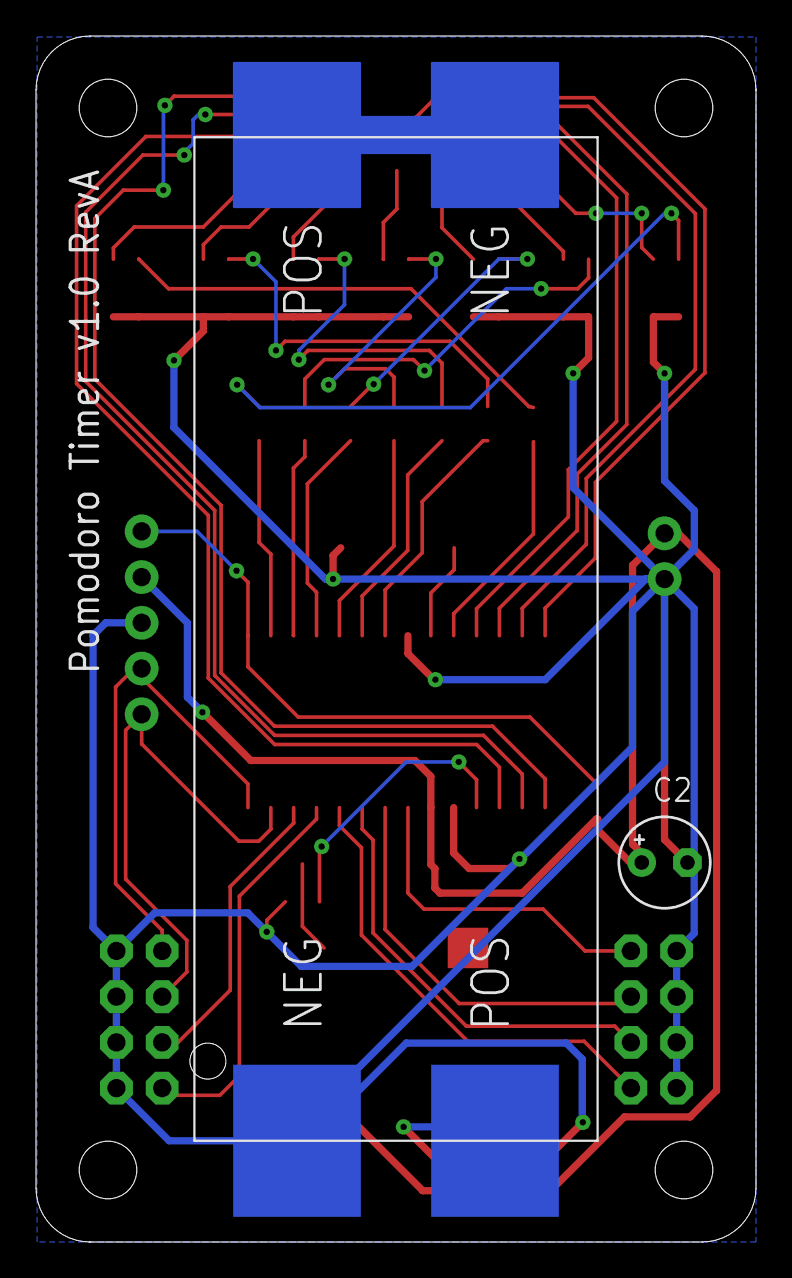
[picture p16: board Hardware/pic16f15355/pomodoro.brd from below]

Board: 2 copper layers, 40.0 x 67.0 mm, 34 parts (2 on the bottom side), 43 nets.

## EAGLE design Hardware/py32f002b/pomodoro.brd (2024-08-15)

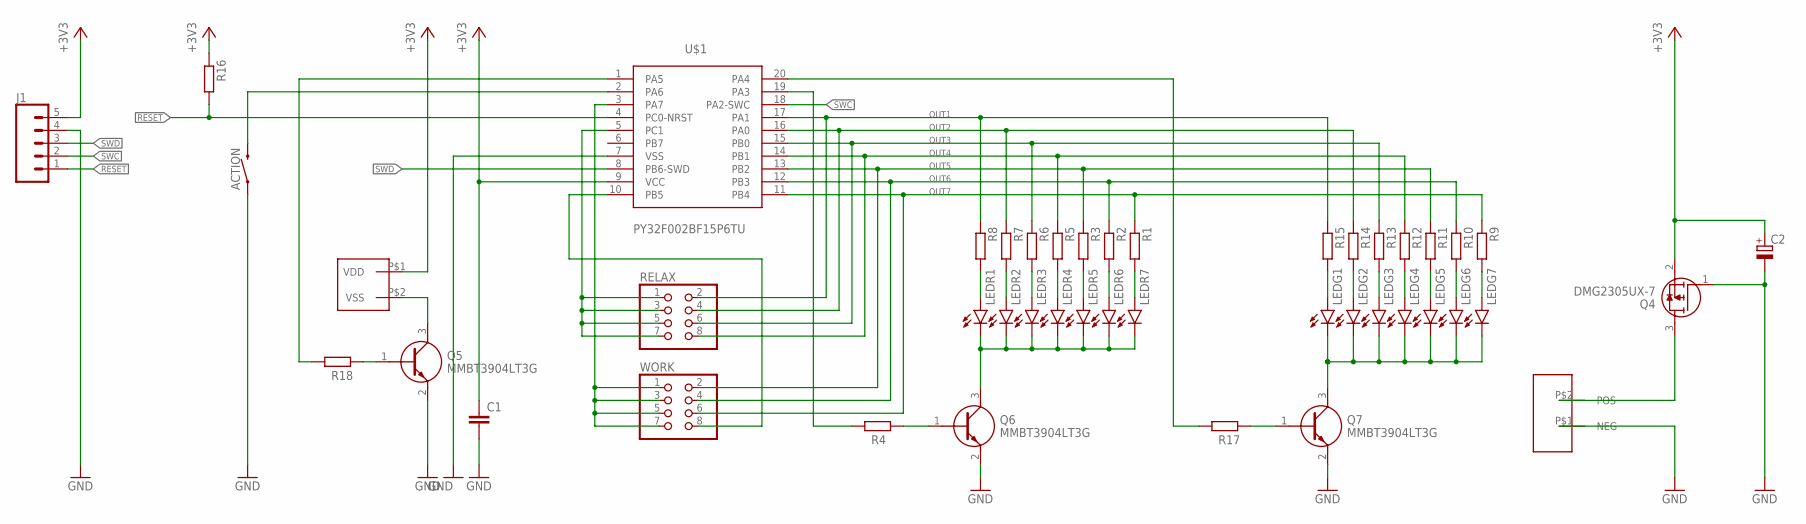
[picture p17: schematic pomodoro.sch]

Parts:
ACTION: MOMENTARY-SWITCH-SPST-SMD-6.0X3.5MM; TACTILE_SWITCH_SMD_6.0X3.5MM
C1: C-EUC0805; C0805
C2: CPOL-EUE2.5-5; E2,5-5
J1: CONN_05; 1X05
LEDG1, LEDG2, LEDG3, LEDG4, LEDG5, LEDG6, LEDG7: 20ma; LED-0603
LEDR1, LEDR2, LEDR3, LEDR4, LEDR5, LEDR6, LEDR7: 20ma; LED-0603
Q4: DMG2305UX-7; SOT96P240X115-3N
Q5, Q6, Q7: MMBT3904LT3G; SOT96P237X111-3N
R1, R2, R3, R5, R6, R7, R8, R9, R10, R11, R12, R13, R14, R15, R16: 100R; R0805
R4, R18: 10k; R0805
R17: 10K; R0805
RELAX: PINHD-2X4; 2X04
U$1: PY32F002BF15P6TU; TSSOP20
U$2: BUZZER8X8
U$3: 2AAABATT; 2AAABATTSER
WORK: PINHD-2X4; 2X04

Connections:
+3V3: C1.1, C2.+, J1.5, Q4.2 (S), R16.1, U$1.9 (VCC), U$2.P$1 (VDD)
BIN: R4.1, U$1.19 (PA3)
BIN1: R17.1, U$1.20 (PA4)
GND: ACTION.1, C1.2, C2.-, J1.4, Q4.1 (G), Q5.2 (E), Q6.2 (E), Q7.2 (E), U$1.7 (VSS), U$3.P$1 (NEG)
LEDR1: LEDR1.A, R8.2
unnamed: LEDG7.A, R9.2
unnamed: LEDG6.A, R10.2
unnamed: LEDG5.A, R11.2
unnamed: LEDG4.A, R12.2
unnamed: LEDG3.A, R13.2
unnamed: Q7.1 (B), R17.2
unnamed: LEDG2.A, R14.2
unnamed: LEDG1.A, R15.2
unnamed: LEDR7.A, R1.2
unnamed: LEDG1.C, LEDG2.C, LEDG3.C, LEDG4.C, LEDG5.C, LEDG6.C, LEDG7.C, Q7.3 (C)
unnamed: LEDR6.A, R2.2
unnamed: LEDR5.A, R3.2
unnamed: LEDR4.A, R5.2
unnamed: LEDR3.A, R6.2
unnamed: LEDR2.A, R7.2
unnamed: Q6.1 (B), R4.2
unnamed: Q5.3 (C), U$2.P$2 (VSS)
unnamed: ACTION.2, U$1.2 (PA6)
unnamed: Q5.1 (B), R18.2
unnamed: R18.1, U$1.1 (PA5)
unnamed: U$1.3 (PA7), WORK.1, WORK.3, WORK.5, WORK.7
unnamed: RELAX.1, RELAX.3, RELAX.5, RELAX.7, U$1.5 (PC1)
unnamed: LEDR1.C, LEDR2.C, LEDR3.C, LEDR4.C, LEDR5.C, LEDR6.C, LEDR7.C, Q6.3 (C)
unnamed: Q4.3 (D), U$3.P$2 (POS)
OUT1: R8.1, R15.1, RELAX.2, U$1.17 (PA1)
OUT2: R7.1, R14.1, RELAX.4, U$1.16 (PA0)
OUT3: R6.1, R13.1, RELAX.6, U$1.15 (PB0)
OUT4: R5.1, R12.1, RELAX.8, U$1.14 (PB1)
OUT5: R3.1, R11.1, U$1.13 (PB2), WORK.2
OUT6: R2.1, R10.1, U$1.12 (PB3), WORK.4
OUT7: R1.1, R9.1, U$1.11 (PB4), WORK.6
OUT8: U$1.10 (PB5), WORK.8
RESET: J1.1, R16.2, U$1.4 (PC0-NRST)
SWC: J1.2, U$1.18 (PA2-SWC)
SWD: J1.3, U$1.8 (PB6-SWD)

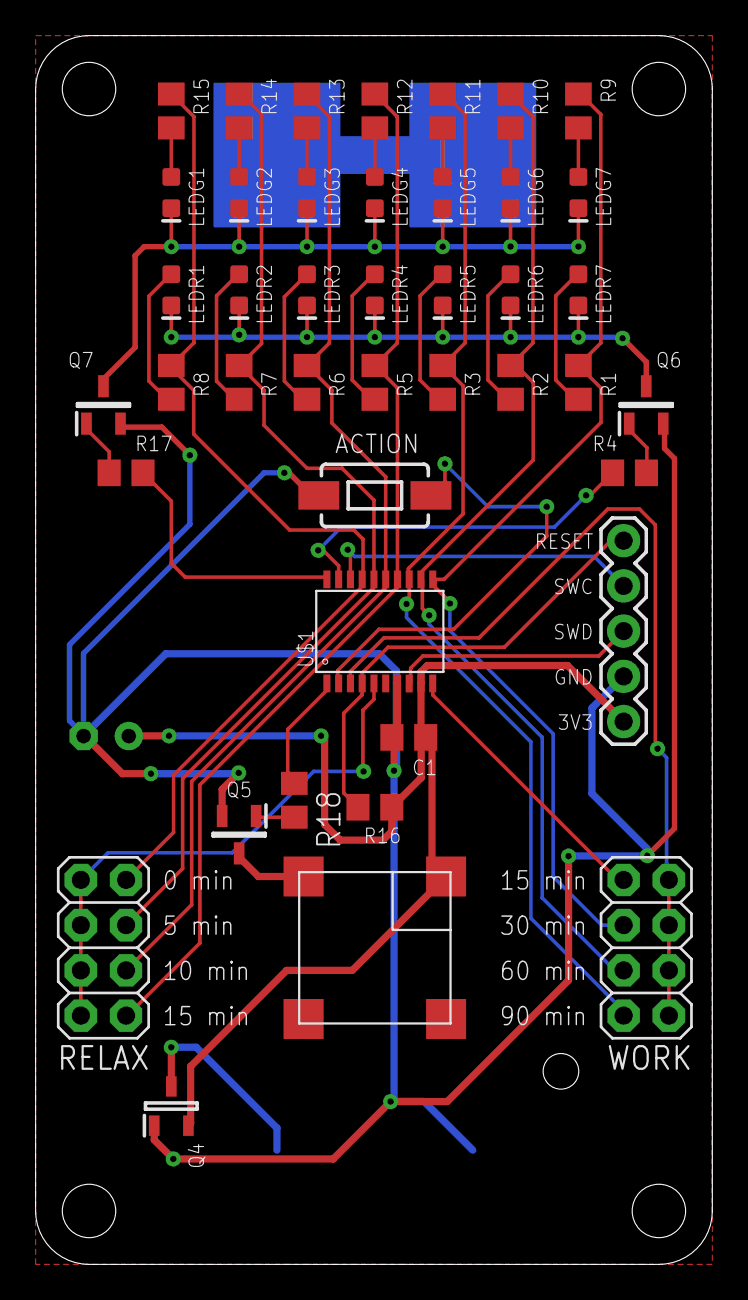
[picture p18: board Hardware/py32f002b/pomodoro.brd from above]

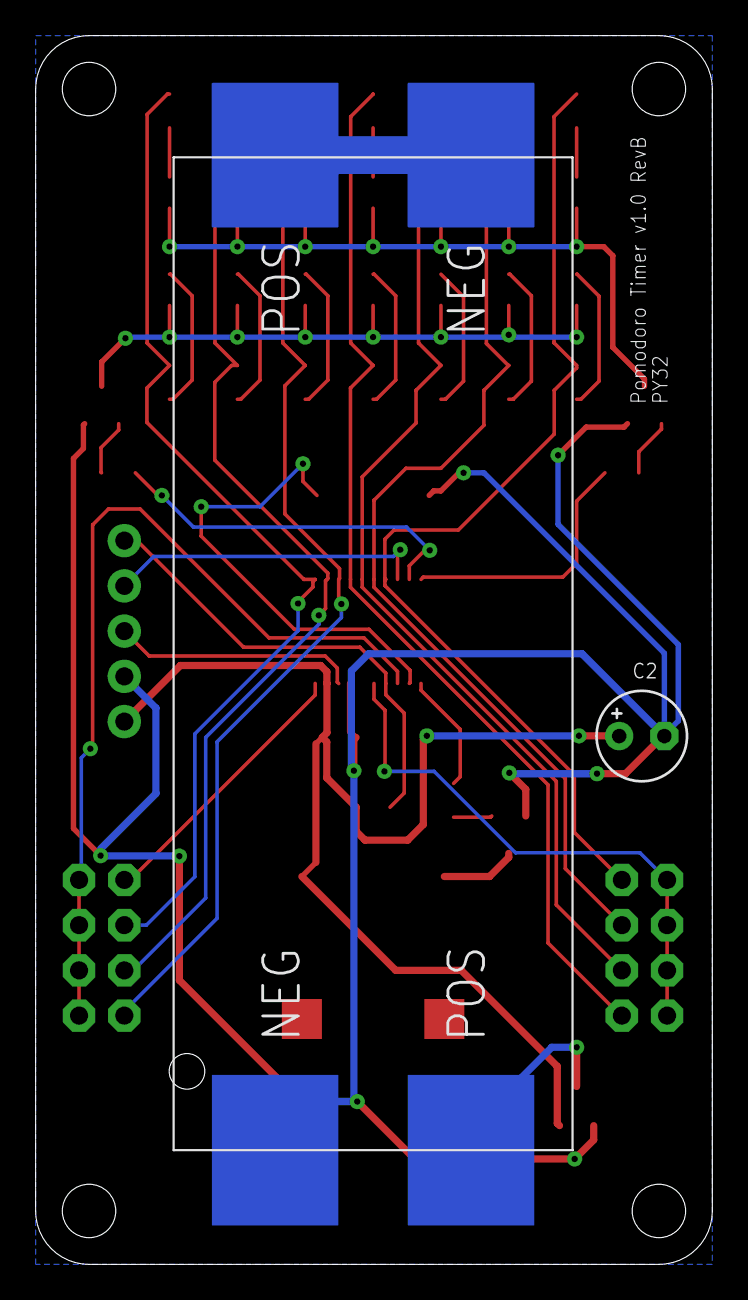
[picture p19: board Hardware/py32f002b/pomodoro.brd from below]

Board: 2 copper layers, 38.0 x 69.0 mm, 45 parts (2 on the bottom side), 40 nets.

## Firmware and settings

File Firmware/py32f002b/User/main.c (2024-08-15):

/**
  ******************************************************************************
  * @file    main.c
  * @author  MCU Application Team
  * @brief   Main program body
  ******************************************************************************
  * @attention
  *
  * <h2><center>&copy; Copyright (c) Puya Semiconductor Co.
  * All rights reserved.</center></h2>
  *
  * <h2><center>&copy; Copyright (c) 2016 STMicroelectronics.
  * All rights reserved.</center></h2>
  *
  * This software component is licensed by ST under BSD 3-Clause license,
  * the "License"; You may not use this file except in compliance with the
  * License. You may obtain a copy of the License at:
  *                        opensource.org/licenses/BSD-3-Clause
  *
  ******************************************************************************
  */

/* Includes ------------------------------------------------------------------*/
#include "main.h"

/* Private define ------------------------------------------------------------*/

/* Private variables ---------------------------------------------------------*/

static volatile uint32_t systickCnt;
static int sleep;

static uint8_t buttonIntegrator;
static uint16_t buttonCount;
static int buttonDstate;

static enum buttonState_e {
    
    BUTTONIDLE=0,
    BUTTONPRESSED,
    BUTTONHELD,
    BUTTONRELEASED,   
            
} buttonState;

static uint32_t workTimeTicks;
static uint32_t relaxTimeTicks;

static enum ledState_e {
    
    STATEWORK=0,
    STATEWORKWAITINGON,
    STATEWORKWAITINGOFF,
    STATERELAX,
    STATERELAXWAITINGON,        
    STATERELAXWAITINGOFF,        
            
} ledState;


/* Private user code ---------------------------------------------------------*/
/* Private macro -------------------------------------------------------------*/

#define ARRAYSIZE(arr) (sizeof(arr) / sizeof(arr[0]))
	
#define MSPERTICK      10
#define MSTOTICKS(x)   ((x)/MSPERTICK)
#define TICKSTOSECS(x) ((x)/(1000/MSPERTICK))

#define DEBOUNCE_TIME               0.05    /* Seconds */
#define DEBOUNCE_SAMPLE_FREQUENCY	100     /* Hertz */

#define DEBOUNCE_MAXIMUM			(DEBOUNCE_TIME * DEBOUNCE_SAMPLE_FREQUENCY)
#define DEBOUNCE_INTEGRATOR_DELAYMS ((1.0/DEBOUNCE_SAMPLE_FREQUENCY)*1000)
#define DEBOUNCE_DELAYMS            (DEBOUNCE_TIME * 1000)

/* Private function prototypes -----------------------------------------------*/

static void APP_SystemClockConfig(void);
static void APP_GpioConfig(void);

static void processButton(void);
static void nullFunc(void);
static void processDisplay(void);
static void processWorkExpired(void);
static void processRelaxExpired(void);
static void processIntegrator(void);
static void buttonReleased(void);
static void buttonHeld(void);
static void buttonPressed(void);
static void buzzStart(void);
static void buzzStop(void);
static void playMelody(void);
static void startMelody(void);
static void stopMelody(void);
static void setupTimer(void);
static void resetAllLeds(void);
static void setAllLeds(void);
static void resetLed(int id);
static void toggleLed(int id);
static void setLed(int id);
static int isWorkTimerSet(void);
static int isRelaxTimerSet(void);
static void getTimers(int *work, int *relax);
static void enableRedLeds(void);
static void disableRedLeds(void);
static void enableGreenLeds(void);
static void disableGreenLeds(void);
static uint32_t getSysTickCnt(void);
static void waitMs(uint32_t msDelay);
static int getButtonValue(void);


static void PWMConfigure(void);
static void TIMConfigure(void);
static void	PWMSetFreq(uint16_t frequency);
static void	PWMPause(void);
static void	PWMUnpause(void);
static void TIMStop(void);
static void PWMStop(void);

static void APP_EnterDeepStop(void);






static struct process_s {
    
    uint32_t periodTick;
    uint32_t lastTick;
    
    void (*func)(void);

} processList[] = {

#ifdef BLINKTEST    
    { (uint32_t)MSTOTICKS(1000),                          0, testFunc          },
#else    
    { (uint32_t)0,                                        0, nullFunc          },
    { (uint32_t)MSTOTICKS(DEBOUNCE_DELAYMS),              0, processButton     },
    { (uint32_t)MSTOTICKS(1000),                          0, processDisplay    },
    { (uint32_t)MSTOTICKS(DEBOUNCE_INTEGRATOR_DELAYMS),   0, processIntegrator },    
    { (uint32_t)MSTOTICKS(50),                            0, playMelody        },
#endif

};


static void setupTimer(void) {
	
		int work, relax;

		getTimers(&work, &relax);
	
		switch (work) {
			case 1:
				workTimeTicks = MSTOTICKS((uint32_t)15*60*1000);  /* 15 mins */
				break;
			case 2:
				workTimeTicks = MSTOTICKS((uint32_t)30*60*1000);  /* 30 mins */
				break;
			case 3:
				workTimeTicks = MSTOTICKS((uint32_t)45*60*1000);  /* 45 mins */
				break;
			case 4:
				workTimeTicks = MSTOTICKS((uint32_t)60*60*1000);  /* 60 mins */
				break;
			default:
				workTimeTicks  = MSTOTICKS((uint32_t)30*60*1000);  /* 30 mins */
				break;
		}
		
		switch (relax) {
			case 1:
				relaxTimeTicks = MSTOTICKS((uint32_t)0*60*1000);  /*  0 mins */
				break;
			case 2:
				relaxTimeTicks = MSTOTICKS((uint32_t)5*60*1000);  /*  5 mins */
				break;
			case 3:
				relaxTimeTicks = MSTOTICKS((uint32_t)10*60*1000); /* 10 mins */
				break;
			case 4:
				relaxTimeTicks = MSTOTICKS((uint32_t)15*60*1000); /* 15 mins */
				break;
			default:
				relaxTimeTicks = MSTOTICKS((uint32_t)0*60*1000);   /*  0 mins */
				break;
		}
}

static void resetAllLeds(void) {

	LL_GPIO_ResetOutputPin(GPIOA, LL_GPIO_PIN_1);
	LL_GPIO_ResetOutputPin(GPIOA, LL_GPIO_PIN_0);
	LL_GPIO_ResetOutputPin(GPIOB, LL_GPIO_PIN_0);
	LL_GPIO_ResetOutputPin(GPIOB, LL_GPIO_PIN_1);
	LL_GPIO_ResetOutputPin(GPIOB, LL_GPIO_PIN_2);
	LL_GPIO_ResetOutputPin(GPIOB, LL_GPIO_PIN_3);
	LL_GPIO_ResetOutputPin(GPIOB, LL_GPIO_PIN_4);
	LL_GPIO_ResetOutputPin(GPIOB, LL_GPIO_PIN_5);
}

static void setAllLeds(void) {

	LL_GPIO_SetOutputPin(GPIOA, LL_GPIO_PIN_1);
	LL_GPIO_SetOutputPin(GPIOA, LL_GPIO_PIN_0);
	LL_GPIO_SetOutputPin(GPIOB, LL_GPIO_PIN_0);
	LL_GPIO_SetOutputPin(GPIOB, LL_GPIO_PIN_1);
	LL_GPIO_SetOutputPin(GPIOB, LL_GPIO_PIN_2);
	LL_GPIO_SetOutputPin(GPIOB, LL_GPIO_PIN_3);
	LL_GPIO_SetOutputPin(GPIOB, LL_GPIO_PIN_4);
	LL_GPIO_SetOutputPin(GPIOB, LL_GPIO_PIN_5);
}





static void toggleLed(int id) {
	
	switch (id) {
		case 1:
			LL_GPIO_TogglePin(GPIOA, LL_GPIO_PIN_1);
			break;
		case 2:
			LL_GPIO_TogglePin(GPIOA, LL_GPIO_PIN_0);
			break;
		case 3:
			LL_GPIO_TogglePin(GPIOB, LL_GPIO_PIN_0);
			break;
		case 4:
			LL_GPIO_TogglePin(GPIOB, LL_GPIO_PIN_1);
			break;
		case 5:
			LL_GPIO_TogglePin(GPIOB, LL_GPIO_PIN_2);
			break;
		case 6:
			LL_GPIO_TogglePin(GPIOB, LL_GPIO_PIN_3);
			break;
		case 7:
			LL_GPIO_TogglePin(GPIOB, LL_GPIO_PIN_4);
			break;
		case 8:
			LL_GPIO_TogglePin(GPIOB, LL_GPIO_PIN_5);
			break;
	}
}


static void resetLed(int id) {
	
	switch (id) {
		case 1:
			LL_GPIO_ResetOutputPin(GPIOA, LL_GPIO_PIN_1);
			break;
		case 2:
			LL_GPIO_ResetOutputPin(GPIOA, LL_GPIO_PIN_0);
			break;
		case 3:
			LL_GPIO_ResetOutputPin(GPIOB, LL_GPIO_PIN_0);
			break;
		case 4:
			LL_GPIO_ResetOutputPin(GPIOB, LL_GPIO_PIN_1);
			break;
		case 5:
			LL_GPIO_ResetOutputPin(GPIOB, LL_GPIO_PIN_2);
			break;
		case 6:
			LL_GPIO_ResetOutputPin(GPIOB, LL_GPIO_PIN_3);
			break;
		case 7:
			LL_GPIO_ResetOutputPin(GPIOB, LL_GPIO_PIN_4);
			break;
		case 8:
			LL_GPIO_ResetOutputPin(GPIOB, LL_GPIO_PIN_5);
			break;
	}
}

static void setLed(int id) {

	switch (id) {
		case 1:
			LL_GPIO_SetOutputPin(GPIOA, LL_GPIO_PIN_1);
			break;
		case 2:
			LL_GPIO_SetOutputPin(GPIOA, LL_GPIO_PIN_0);
			break;
		case 3:
			LL_GPIO_SetOutputPin(GPIOB, LL_GPIO_PIN_0);
			break;
		case 4:
			LL_GPIO_SetOutputPin(GPIOB, LL_GPIO_PIN_1);
			break;
		case 5:
			LL_GPIO_SetOutputPin(GPIOB, LL_GPIO_PIN_2);
			break;
		case 6:
			LL_GPIO_SetOutputPin(GPIOB, LL_GPIO_PIN_3);
			break;
		case 7:
			LL_GPIO_SetOutputPin(GPIOB, LL_GPIO_PIN_4);
			break;
		case 8:
			LL_GPIO_SetOutputPin(GPIOB, LL_GPIO_PIN_5);
			break;
	}
}

static int isWorkTimerSet(void) {
	
	return LL_GPIO_IsInputPinSet(GPIOA, LL_GPIO_PIN_7);
}

static int isRelaxTimerSet(void) {
	
	return LL_GPIO_IsInputPinSet(GPIOC, LL_GPIO_PIN_1);
}


static void getTimers(int *work, int *relax) {
	
	*work = 0;
	*relax = 0;
	
	resetAllLeds();

	/* WORK Timer Inputs */
	LL_GPIO_SetPinPull(GPIOA, LL_GPIO_PIN_7, LL_GPIO_PULL_DOWN);
	LL_GPIO_SetPinMode(GPIOA, LL_GPIO_PIN_7, LL_GPIO_MODE_INPUT);
	
	/* RELAX Timer Inputs */
	LL_GPIO_SetPinPull(GPIOC, LL_GPIO_PIN_1, LL_GPIO_PULL_DOWN);
	LL_GPIO_SetPinMode(GPIOC, LL_GPIO_PIN_1, LL_GPIO_MODE_INPUT);

	
	for (int i=1; i<9; i++) {
		
		setLed(i);
		if (isRelaxTimerSet()) {
			*relax = i;
		}
		if (isWorkTimerSet()) {
			*work = i;
		}
		resetLed(i);
	}	


	/* WORK Timer Ouput */
	LL_GPIO_SetPinPull(GPIOA, LL_GPIO_PIN_7, LL_GPIO_PULL_NO);
	LL_GPIO_SetPinMode(GPIOA, LL_GPIO_PIN_7, LL_GPIO_MODE_ANALOG);
	/* RELAX Timer Ouput */
	LL_GPIO_SetPinPull(GPIOC, LL_GPIO_PIN_1, LL_GPIO_PULL_NO);
	LL_GPIO_SetPinMode(GPIOC, LL_GPIO_PIN_1, LL_GPIO_MODE_ANALOG);




}

static void enableRedLeds(void) {
	LL_GPIO_SetOutputPin(GPIOA, LL_GPIO_PIN_3);
}

static void disableRedLeds(void) {
	LL_GPIO_ResetOutputPin(GPIOA, LL_GPIO_PIN_3);
}

static void enableGreenLeds(void) {
	LL_GPIO_SetOutputPin(GPIOA, LL_GPIO_PIN_4);
}

static void disableGreenLeds(void) {
	LL_GPIO_ResetOutputPin(GPIOA, LL_GPIO_PIN_4);
}

static volatile uint32_t systickCnt = 0;

void SysTick_Handler(void) {
  systickCnt++;
}

static uint32_t getSysTickCnt(void) {
	return systickCnt;
}

static void waitMs(uint32_t msDelay) {

	if (msDelay == 0) return;
		
	uint32_t delayCount = ((msDelay-1) / 10) + 1;
	uint32_t start = getSysTickCnt();
	
	while (1) {		
		if (getSysTickCnt() - start > delayCount) {
			break;
		}
	}	
}





static void nullFunc(void){
    
}

static void buzzStart(void) {
	//TODO

    return;
    
}

static void buzzStop(void) {
	//TODO
    
    return;
}





static void processIntegrator(void) {

    /* This function MUST be called every 1/DEBOUNCE_SAMPLE_FREQUENCY seconds
     */
    if (getButtonValue() != 0) {                
        if (buttonIntegrator > 0) {                
            buttonIntegrator--;
        }                               
    } else if (buttonIntegrator < DEBOUNCE_MAXIMUM) {
        buttonIntegrator++;
    }
}

static void buttonReleased(void) {

    if (sleep) {

        APP_EnterDeepStop();

        /* An interrupt has woken us up from sleep */
        
        __NOP();
        __NOP();
        __NOP();

        /* restart */
        
        NVIC_SystemReset();
    }
}


static void buttonHeld(void) {
    
    /* Test to see if the button has been held down for 3 seconds.
     * If it has then we shutdown 
     */    
        
    if (buttonCount > ((3 * 1000) / DEBOUNCE_DELAYMS)) {

        resetAllLeds();

				disableRedLeds();
				disableGreenLeds();
			
        PWMStop();
        TIMStop();

        /* Signal that we want to enter sleep */
        
        sleep = 1;			
    }    
}

static void buttonPressed(void) {

    /* The button was pressed, this is only relevant when the 
     * we are blinking in the work/relax state, if we are then
     * we can reset the time and switch state.
     */    
    switch (ledState) {
        case STATEWORK:
            break;
        case STATEWORKWAITINGON:
        case STATEWORKWAITINGOFF:

            buzzStop();
            stopMelody();
                        
            processList[0].periodTick = relaxTimeTicks;
            processList[0].lastTick   = systickCnt;
            processList[0].func       = processRelaxExpired;

						resetAllLeds();
						disableRedLeds();
						enableGreenLeds();
				
            ledState = STATERELAX;
            break;

        case STATERELAX:
            break;
        case STATERELAXWAITINGON:
        case STATERELAXWAITINGOFF:

            buzzStop();
            stopMelody();

            processList[0].periodTick = workTimeTicks;
            processList[0].lastTick   = systickCnt;
            processList[0].func       = processWorkExpired;

						resetAllLeds();
						disableGreenLeds();
						enableRedLeds();
				
            ledState = STATEWORK;
            break;
    }
}
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
int main(void)
{
		/* Configure HSI as Systemclock source */
		APP_SystemClockConfig();

		/* Fixme! hardcoded 24Mhz */
		LL_InitTick(SYSTEMCLOCK, 100);  /* 10ms Tick */
		LL_SYSTICK_EnableIT();


		/* Configure GPIO Pins */
		APP_GpioConfig();

		
		
		/* Setup PWM hardware */
		TIMConfigure();
		PWMConfigure();	
		
	  /* Wait 1 second for any button bouncing to settle after reset, we may have
     * just been woken with a button press and need to filter it out
     */
	
    while (getButtonValue() == 0) {
        waitMs(100);        
    }

	
#ifndef BLINKTEST
    /* Read the pin to determine work time and relax time */
    setupTimer();
    
    /* Setup our initial work/relax state, waiting in relaxed state for button 
     * press 
     */   
    processList[0].periodTick = relaxTimeTicks;
    processList[0].lastTick   = systickCnt;
    processList[0].func       = processRelaxExpired;
    
		resetAllLeds();
		disableRedLeds();
		enableGreenLeds();

    ledState = STATERELAXWAITINGON;
    
#endif

    
    startMelody();
    
    /* Main loop scheduling processes */
    while (1) {
                
        /* Step through each process and test if period has expired and
         * if has, dispatch the function and adjust it last run time
         */        
        for (uint32_t i=0; i<ARRAYSIZE(processList); i++) {
            
            if ((uint32_t)(systickCnt - processList[i].lastTick) >= processList[i].periodTick) {
                
                (*processList[i].func)();
                processList[i].lastTick = systickCnt;
            }
        }        
    }    
}

/**
  * @brief  Configure HSI as Systemclock source
  * @param  None
  * @retval None
  */
static void APP_SystemClockConfig(void)
{
  /* Enable HSI */
  LL_RCC_HSI_Enable();
  while(LL_RCC_HSI_IsReady() != 1)
  {
  }

  /* Set AHB divider: HCLK = SYSCLK */
  LL_RCC_SetAHBPrescaler(LL_RCC_SYSCLK_DIV_1);

  /* HSISYS used as SYSCLK clock source  */
  LL_RCC_SetSysClkSource(LL_RCC_SYS_CLKSOURCE_HSISYS);
  while(LL_RCC_GetSysClkSource() != LL_RCC_SYS_CLKSOURCE_STATUS_HSISYS)
  {
  }

  /* Set APB1 divider */
  LL_RCC_SetAPB1Prescaler(LL_RCC_APB1_DIV_1);
  LL_Init1msTick(SYSTEMCLOCK);

  /* Update CMSIS variable (which can be updated also through SystemCoreClockUpdate function) */
  LL_SetSystemCoreClock(SYSTEMCLOCK);
}

/**
  * @brief  GPIO configuration program
  * @param  None
  * @retval None
  */
static void APP_GpioConfig(void)
{
    LL_EXTI_InitTypeDef EXTI_InitStruct = {0};

    /* Enable GPIO clocks */
    LL_IOP_GRP1_EnableClock(LL_IOP_GRP1_PERIPH_GPIOA);
    LL_IOP_GRP1_EnableClock(LL_IOP_GRP1_PERIPH_GPIOB);
    LL_IOP_GRP1_EnableClock(LL_IOP_GRP1_PERIPH_GPIOC);

	
	/*
	
	Output PA1 - OUT1 - LEDR1, LEDG1
	Output PA0 - OUT2 - LEDR2, LEDG2
	Output PB0 - OUT3 - LEDR3, LEDG3
	Output PB1 - OUT4 - LEDR4, LEDG4
	Output PB2 - OUT5 - LEDR5, LEDG5
	Output PB3 - OUT6 - LEDR6, LEDG6
	Output PB4 - OUT7 - LEDR7, LEDG7
	Output PB5 - OUT8
	
	
	
	Input PA3 - Enable RED LEDs
	Input PA4 - Enable GREEN LEDs
	Input PA6 - Button

	Output PA5 - Buzzer
	
	*/
	
	LL_GPIO_SetPinMode(GPIOA, LL_GPIO_PIN_1, LL_GPIO_MODE_OUTPUT);
	LL_GPIO_SetPinMode(GPIOA, LL_GPIO_PIN_0, LL_GPIO_MODE_OUTPUT);
	LL_GPIO_SetPinMode(GPIOB, LL_GPIO_PIN_0, LL_GPIO_MODE_OUTPUT);
	LL_GPIO_SetPinMode(GPIOB, LL_GPIO_PIN_1, LL_GPIO_MODE_OUTPUT);
	LL_GPIO_SetPinMode(GPIOB, LL_GPIO_PIN_2, LL_GPIO_MODE_OUTPUT);
	LL_GPIO_SetPinMode(GPIOB, LL_GPIO_PIN_3, LL_GPIO_MODE_OUTPUT);
	LL_GPIO_SetPinMode(GPIOB, LL_GPIO_PIN_4, LL_GPIO_MODE_OUTPUT);
	LL_GPIO_SetPinMode(GPIOB, LL_GPIO_PIN_5, LL_GPIO_MODE_OUTPUT);
	
	LL_GPIO_SetPinMode(GPIOA, LL_GPIO_PIN_3, LL_GPIO_MODE_OUTPUT);
	LL_GPIO_SetPinMode(GPIOA, LL_GPIO_PIN_4, LL_GPIO_MODE_OUTPUT);

	/* Buzzer */
	LL_GPIO_SetPinMode(GPIOA, LL_GPIO_PIN_5, LL_GPIO_MODE_OUTPUT);
	
	/* WORK Timer Inputs */
	LL_GPIO_SetPinPull(GPIOA, LL_GPIO_PIN_7, LL_GPIO_PULL_DOWN);
	LL_GPIO_SetPinMode(GPIOA, LL_GPIO_PIN_7, LL_GPIO_MODE_INPUT);
	
	/* RELAX Timer Inputs */
	LL_GPIO_SetPinPull(GPIOC, LL_GPIO_PIN_1, LL_GPIO_PULL_DOWN);
	LL_GPIO_SetPinMode(GPIOC, LL_GPIO_PIN_1, LL_GPIO_MODE_INPUT);
	
	/* Button input */
	LL_GPIO_SetPinPull(GPIOA, LL_GPIO_PIN_6, LL_GPIO_PULL_UP);
	LL_GPIO_SetPinMode(GPIOA, LL_GPIO_PIN_6, LL_GPIO_MODE_INPUT);	

    /* Register interrupt handler for Butto so we can wake from sleep */
    /* Configure PA6 as the EXTI6 interrupt input */
    LL_EXTI_SetEXTISource(LL_EXTI_CONFIG_PORTA, LL_EXTI_CONFIG_LINE6);

    /* Enable EXTI6 */
    EXTI_InitStruct.Line = LL_EXTI_LINE_6;
    EXTI_InitStruct.LineCommand = ENABLE;
    /* Event mode */
    EXTI_InitStruct.Mode = LL_EXTI_MODE_EVENT;
    /* Trigger Falling Mode */
    EXTI_InitStruct.Trigger = LL_EXTI_TRIGGER_FALLING;
    /* Initialize the EXTI registers according to the specified parameters in EXTI_InitStruct  */
    LL_EXTI_Init(&EXTI_InitStruct);
}


/* To simplify this implementation we have set the 
 * Lower and upperbounds to 366 Hz and 65536 Hz respectively.
 *
 * Min value for frequency is   366 Hz
 * Max value for frequency is 65536 Hz
 */
static int isPaused = 0;

static void	PWMSetFreq(uint16_t frequency) {

		if (frequency < 366) {

			PWMPause();

		} else {
	
				PWMUnpause();

				uint16_t prescaler = (SYSTEMCLOCK / 2) / frequency;
										
				LL_TIM_SetPrescaler(TIM1, prescaler);
				LL_TIM_SetAutoReload(TIM1, 2);
				LL_TIM_OC_SetCompareCH1(TIM1, 1); /* 50 % duty */				
		}
}

static void	PWMPause(void) {
	
		if (isPaused) return;

		LL_GPIO_SetPinMode(GPIOA, LL_GPIO_PIN_5, LL_GPIO_MODE_OUTPUT);
		LL_GPIO_ResetOutputPin(GPIOA, LL_GPIO_PIN_5);
		
		isPaused = 1;		
}

static void	PWMUnpause(void) {

		if (!isPaused) return;
	
		LL_GPIO_InitTypeDef GpioInit = {0};

		GpioInit.Pin = LL_GPIO_PIN_5;
		GpioInit.Mode = LL_GPIO_MODE_ALTERNATE;
		GpioInit.Alternate = LL_GPIO_AF_2;
		LL_GPIO_Init(GPIOA, &GpioInit);

		isPaused = 0;
}


static void PWMConfigure(void)
{
	// PA5 is PWM output TIM1_CH1 its initial state is 
	// configured as a simple output pulled low
	
  LL_TIM_OC_InitTypeDef TIM_OC_Initstruct = {0};
	
  TIM_OC_Initstruct.OCMode = LL_TIM_OCMODE_PWM1;
  TIM_OC_Initstruct.OCState = LL_TIM_OCSTATE_ENABLE;
  TIM_OC_Initstruct.OCPolarity = LL_TIM_OCPOLARITY_HIGH;
  TIM_OC_Initstruct.OCIdleState = LL_TIM_OCIDLESTATE_LOW;

  /* Set channel compare value */	
  TIM_OC_Initstruct.CompareValue = 0; // 50% duty cycle
  LL_TIM_OC_Init(TIM1, LL_TIM_CHANNEL_CH1, &TIM_OC_Initstruct);	

	/* Set to initial state to paused and pulled low.
	 * To start the PWM on the output pin call PWMUnpause()
	 */
	isPaused = 1;		
}

static void PWMStop(void)
{	
	PWMPause();
}

static void TIMConfigure(void)
{
  LL_TIM_InitTypeDef TIM1CountInit = {0};
	
	LL_APB1_GRP2_EnableClock(LL_APB1_GRP2_PERIPH_TIM1);
	 
  TIM1CountInit.ClockDivision       = LL_TIM_CLOCKDIVISION_DIV1;
  TIM1CountInit.CounterMode         = LL_TIM_COUNTERMODE_UP;
  TIM1CountInit.Prescaler           = (SYSTEMCLOCK / 2) / 25000; 
  TIM1CountInit.Autoreload          = 2;
  TIM1CountInit.RepetitionCounter   = 1; /* 25 KHz with 50% Duty cycle */   
  LL_TIM_Init(TIM1,&TIM1CountInit);    

  LL_TIM_EnableAllOutputs(TIM1);
  LL_TIM_EnableCounter(TIM1);
}

static void TIMStop(void)
{	
	LL_TIM_DisableCounter(TIM1);
	LL_TIM_DisableAllOutputs(TIM1);

  LL_TIM_DeInit(TIM1);
	
	LL_APB1_GRP2_DisableClock(LL_APB1_GRP2_PERIPH_TIM1);
}

static void APP_EnterDeepStop(void)
{
  /* Enable PWR clock */
  LL_APB1_GRP1_EnableClock(LL_APB1_GRP1_PERIPH_PWR);

  /* STOP mode with deep low power regulator ON */
  LL_PWR_SetLprMode(LL_PWR_LPR_MODE_DLPR);

  /* SRAM retention voltage aligned with digital LDO output */
  LL_PWR_SetStopModeSramVoltCtrl(LL_PWR_SRAM_RETENTION_VOLT_CTRL_LDO);

  /* Enter DeepSleep mode */
  LL_LPM_EnableDeepSleep();

  /* Request Wait For Event */
   __SEV();
   __WFE();
   __WFE();

   LL_LPM_EnableSleep();
}



/**
  * @brief  Error handling function
  * @param  None
  * @retval None
  */
void APP_ErrorHandler(void)
{
  /* Infinite loop */
  while (1)
  {
  }
}

#ifdef  USE_FULL_ASSERT
/**
  * @brief  Reports the name of the source file and the source line number
  *         where the assert_param error has occurred.
  * @param  file：Pointer to the source file name
  * @param  line：assert_param error line source number
  * @retval None
  */
void assert_failed(uint8_t *file, uint32_t line)
{
  /* User can add His own implementation to report the file name and line number,
     tex: printf("Wrong parameters value: file %s on line %d\r\n", file, line) */
  /* Infinite loop */
  while (1)
  {
  }
}
#endif /* USE_FULL_ASSERT */

/************************ (C) COPYRIGHT Puya *****END OF FILE******************/

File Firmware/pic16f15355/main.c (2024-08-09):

/**
  Generated Main Source File

  Company:
    Microchip Technology Inc.

  File Name:
    main.c

  Summary:
    This is the main file generated using PIC10 / PIC12 / PIC16 / PIC18 MCUs

  Description:
    This header file provides implementations for driver APIs for all modules selected in the GUI.
    Generation Information :
        Product Revision  :  PIC10 / PIC12 / PIC16 / PIC18 MCUs - 1.81.8
        Device            :  PIC16F15355
        Driver Version    :  2.00
*/

/*
    (c) 2018 Microchip Technology Inc. and its subsidiaries. 
    
    Subject to your compliance with these terms, you may use Microchip software and any 
    derivatives exclusively with Microchip products. It is your responsibility to comply with third party 
    license terms applicable to your use of third party software (including open source software) that 
    may accompany Microchip software.
    
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
    IN NO EVENT WILL MICROCHIP BE LIABLE FOR ANY INDIRECT, SPECIAL, PUNITIVE, 
    INCIDENTAL OR CONSEQUENTIAL LOSS, DAMAGE, COST OR EXPENSE OF ANY KIND 
    WHATSOEVER RELATED TO THE SOFTWARE, HOWEVER CAUSED, EVEN IF MICROCHIP 
    HAS BEEN ADVISED OF THE POSSIBILITY OR THE DAMAGES ARE FORESEEABLE. TO 
    THE FULLEST EXTENT ALLOWED BY LAW, MICROCHIP'S TOTAL LIABILITY ON ALL 
    CLAIMS IN ANY WAY RELATED TO THIS SOFTWARE WILL NOT EXCEED THE AMOUNT 
    OF FEES, IF ANY, THAT YOU HAVE PAID DIRECTLY TO MICROCHIP FOR THIS 
    SOFTWARE.
*/

#include "mcc_generated_files/mcc.h"

//#define BLINKTEST 1

#define ARRAYSIZE(arr) (sizeof(arr) / sizeof(arr[0]))        

static void timerInterrupt(void);
static void processButton(void);
static void nullFunc(void);
static void processDisplay(void);
static void processWorkExpired(void);
static void processRelaxExpired(void);
static void processIntegrator(void);
static void buttonReleased(void);
static void buttonHeld(void);
static void buttonPressed(void);
static void buzzStart(void);
static void buzzStop(void);
static void playMelody(void);
static void startMelody(void);
static void stopMelody(void);


#define MSPERTICK      10
#define MSTOTICKS(x)   ((x)/MSPERTICK)
#define TICKSTOSECS(x) ((x)/(1000/MSPERTICK))

static volatile uint32_t sysTick;
static bool sleep;

static uint8_t buttonIntegrator;
static uint16_t buttonCount;
static bool buttonDstate;

#define DEBOUNCE_TIME               0.05    /* Seconds */
#define DEBOUNCE_SAMPLE_FREQUENCY	100     /* Hertz */

#define DEBOUNCE_MAXIMUM			(DEBOUNCE_TIME * DEBOUNCE_SAMPLE_FREQUENCY)
#define DEBOUNCE_INTEGRATOR_DELAYMS ((1.0/DEBOUNCE_SAMPLE_FREQUENCY)*1000)
#define DEBOUNCE_DELAYMS            (DEBOUNCE_TIME * 1000)

static enum buttonState_e {
    
    BUTTONIDLE=0,
    BUTTONPRESSED,
    BUTTONHELD,
    BUTTONRELEASED,   
            
} buttonState;

#ifdef BLINKTEST
static void testFunc(void) {
    
    IO_LEDG0_Toggle();    
    IO_LEDG1_Toggle();    
}
#endif

static struct process_s {
    
    uint32_t periodTick;
    uint32_t lastTick;
    
    void (*func)(void);

} processList[] = {

#ifdef BLINKTEST    
    { (uint32_t)MSTOTICKS(1000),                          0, testFunc          },
#else    
    { (uint32_t)0,                                        0, nullFunc          },
    { (uint32_t)MSTOTICKS(DEBOUNCE_DELAYMS),              0, processButton     },
    { (uint32_t)MSTOTICKS(1000),                          0, processDisplay    },
    { (uint32_t)MSTOTICKS(DEBOUNCE_INTEGRATOR_DELAYMS),   0, processIntegrator },    
    { (uint32_t)MSTOTICKS(50),                            0, playMelody        },
#endif

};

static uint32_t workTimeTicks;
static uint32_t relaxTimeTicks;

static enum ledState_e {
    
    STATEWORK=0,
    STATEWORKWAITINGON,
    STATEWORKWAITINGOFF,
    STATERELAX,
    STATERELAXWAITINGON,        
    STATERELAXWAITINGOFF,        
            
} ledState;

static void timerInterrupt(void) {
 
    /* We are called every system tick */
    
    sysTick++;
}

void setupTimer(void) {

    /* defaults */
    
    workTimeTicks  = MSTOTICKS((uint32_t)30*60*1000);  /* 30 mins */
    relaxTimeTicks = MSTOTICKS((uint32_t)0*60*1000);   /*  0 mins */
        
    /* Read Work Time */
    
    if (IO_WORK0_GetValue() == 0) {
        workTimeTicks = MSTOTICKS((uint32_t)15*60*1000);  /* 15 mins */
    }
    else if (IO_WORK1_GetValue() == 0) {
        workTimeTicks = MSTOTICKS((uint32_t)30*60*1000);  /* 30 mins */
    }
    else if (IO_WORK2_GetValue() == 0) {
        workTimeTicks = MSTOTICKS((uint32_t)45*60*1000);  /* 45 mins */
    }
    else if (IO_WORK3_GetValue() == 0) {
        workTimeTicks = MSTOTICKS((uint32_t)60*60*1000);  /* 60 mins */
    }
        
    /* Read Relax Time*/

    if (IO_RELAX0_GetValue() == 0) {   
        relaxTimeTicks = MSTOTICKS((uint32_t)0*60*1000);  /*  0 mins */
    }
    else if (IO_RELAX1_GetValue() == 0) {
        relaxTimeTicks = MSTOTICKS((uint32_t)5*60*1000);  /*  5 mins */
    }
    else if (IO_RELAX2_GetValue() == 0) {
        relaxTimeTicks = MSTOTICKS((uint32_t)10*60*1000); /* 10 mins */
    }
    else if (IO_RELAX3_GetValue() == 0) {
        relaxTimeTicks = MSTOTICKS((uint32_t)15*60*1000); /* 15 mins */
    }
}

static void nullFunc(void){
    
}

static void buzzStart(void) {

    return;
    
    /* PWM3POL active_hi; PWM3EN enabled; */
    PWM3CON = 0x80;   
}

static void buzzStop(void) {
    
    return;

    /* PWM3POL active_hi; PWM3EN disabled; */
    PWM3CON = 0x00;   
}

static void processIntegrator(void) {

    /* This function MUST be called every 1/DEBOUNCE_SAMPLE_FREQUENCY seconds
     */
    if (IO_BUTTON_GetValue() != 0) {                
        if (buttonIntegrator > 0) {                
            buttonIntegrator--;
        }                               
    } else if (buttonIntegrator < DEBOUNCE_MAXIMUM) {
        buttonIntegrator++;
    }
}

static void buttonReleased(void) {

    if (sleep) {

        /* Stop our system timer */
        
        TMR0_StopTimer();

        /* Wait for any button bouncing to settle */

        __delay_ms(1000);

        /* Go to sleep, the only interrupt active should be on our button */
        
        SLEEP();

        /* An interrupt has woken us up from sleep */
        
        NOP();
        NOP();
        NOP();

        /* restart */
        
        RESET();
    }
}

static void buttonHeld(void) {
    
    /* Test to see if the button has been held down for 3 seconds.
     * If it has then we shutdown 
     */    
        
    if (buttonCount > ((3 * 1000) / DEBOUNCE_DELAYMS)) {
        
        /* Turn off ALL LEDs */
        
        LATA &= 0x80;
        LATC &= 0x80;        
        
        buzzStop();

        /* Stop melody */

        /* Disable PWM */
        PWM3CONbits.PWM3EN = 0;

        /* Stop Timer */
        TMR2_Stop();



        
        /* Signal that we want to enter sleep */
        
        sleep = 1;        
    }    
}
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

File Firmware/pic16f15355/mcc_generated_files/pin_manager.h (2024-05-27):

/**
  @Generated Pin Manager Header File

  @Company:
    Microchip Technology Inc.

  @File Name:
    pin_manager.h

  @Summary:
    This is the Pin Manager file generated using PIC10 / PIC12 / PIC16 / PIC18 MCUs

  @Description
    This header file provides APIs for driver for .
    Generation Information :
        Product Revision  :  PIC10 / PIC12 / PIC16 / PIC18 MCUs - 1.81.8
        Device            :  PIC16F15355
        Driver Version    :  2.11
    The generated drivers are tested against the following:
        Compiler          :  XC8 2.36 and above
        MPLAB 	          :  MPLAB X 6.00	
*/

/*
    (c) 2018 Microchip Technology Inc. and its subsidiaries. 
    
    Subject to your compliance with these terms, you may use Microchip software and any 
    derivatives exclusively with Microchip products. It is your responsibility to comply with third party 
    license terms applicable to your use of third party software (including open source software) that 
    may accompany Microchip software.
    
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
    IN NO EVENT WILL MICROCHIP BE LIABLE FOR ANY INDIRECT, SPECIAL, PUNITIVE, 
    INCIDENTAL OR CONSEQUENTIAL LOSS, DAMAGE, COST OR EXPENSE OF ANY KIND 
    WHATSOEVER RELATED TO THE SOFTWARE, HOWEVER CAUSED, EVEN IF MICROCHIP 
    HAS BEEN ADVISED OF THE POSSIBILITY OR THE DAMAGES ARE FORESEEABLE. TO 
    THE FULLEST EXTENT ALLOWED BY LAW, MICROCHIP'S TOTAL LIABILITY ON ALL 
    CLAIMS IN ANY WAY RELATED TO THIS SOFTWARE WILL NOT EXCEED THE AMOUNT 
    OF FEES, IF ANY, THAT YOU HAVE PAID DIRECTLY TO MICROCHIP FOR THIS 
    SOFTWARE.
*/

#ifndef PIN_MANAGER_H
#define PIN_MANAGER_H

/**
  Section: Included Files
*/

#include <xc.h>

#define INPUT   1
#define OUTPUT  0

#define HIGH    1
#define LOW     0

#define ANALOG      1
#define DIGITAL     0

#define PULL_UP_ENABLED      1
#define PULL_UP_DISABLED     0

// get/set IO_LEDR0 aliases
#define IO_LEDR0_TRIS                 TRISAbits.TRISA0
#define IO_LEDR0_LAT                  LATAbits.LATA0
#define IO_LEDR0_PORT                 PORTAbits.RA0
#define IO_LEDR0_WPU                  WPUAbits.WPUA0
#define IO_LEDR0_OD                   ODCONAbits.ODCA0
#define IO_LEDR0_ANS                  ANSELAbits.ANSA0
#define IO_LEDR0_SetHigh()            do { LATAbits.LATA0 = 1; } while(0)
#define IO_LEDR0_SetLow()             do { LATAbits.LATA0 = 0; } while(0)
#define IO_LEDR0_Toggle()             do { LATAbits.LATA0 = ~LATAbits.LATA0; } while(0)
#define IO_LEDR0_GetValue()           PORTAbits.RA0
#define IO_LEDR0_SetDigitalInput()    do { TRISAbits.TRISA0 = 1; } while(0)
#define IO_LEDR0_SetDigitalOutput()   do { TRISAbits.TRISA0 = 0; } while(0)
#define IO_LEDR0_SetPullup()          do { WPUAbits.WPUA0 = 1; } while(0)
#define IO_LEDR0_ResetPullup()        do { WPUAbits.WPUA0 = 0; } while(0)
#define IO_LEDR0_SetPushPull()        do { ODCONAbits.ODCA0 = 0; } while(0)
#define IO_LEDR0_SetOpenDrain()       do { ODCONAbits.ODCA0 = 1; } while(0)
#define IO_LEDR0_SetAnalogMode()      do { ANSELAbits.ANSA0 = 1; } while(0)
#define IO_LEDR0_SetDigitalMode()     do { ANSELAbits.ANSA0 = 0; } while(0)
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

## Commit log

2024-05-25 Project checkin
    Project checkin after repository creation
    [pomodoro.brd, pomodoro.sch]
2024-05-25 Added hardware BOM, gerbers and images
    [BOM.csv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]
2024-05-27 Added docs, images and cad libraries
2024-05-27 Work on sleep
    Add interrupt on change to button, add button logic to sleep and wakup
2024-05-27 Filter any button press at startup from sleep
2024-05-30 Switched out diode and added pchannel mosfet, rounded corners, generated new gergbers
    [pomodoro.brd, pomodoro.sch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]
2024-06-01 Checked nets Added 3dmodels, moved buzzer to centre and replaced 2mm holes with 3.2mm generated images and gerbers
    [APBD3224LSURKCGKC.stp, CMI-8536-82-SMT-TR.stp, CUS10S30,H3F.stp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]
2024-06-01 Updated BOM and Added docs for mosfets
    [BOM.csv]
2024-06-03 Invert LEDs, fix incorrect comments and make time delay more human readable
    [main.c]
2024-06-03 Added gerbers to zip file to uploads to manufacturer
2024-06-04 Change order that LEDs countdown, ensure we clear old LEDs
2024-06-04 Changed buzzer ouput to PWM with 2.5KHz freq and 50% duty cycle
    [main.c]
2024-06-04 Start and Stop Buzzer in sycn with flashing LEDs
    [main.c]
2024-06-12 Added duration for notes in melody, we now start melody on blink leds and do not loop the melody, it plays once on blink start
2024-06-25 Populated Board
2024-08-04 initial checkin py32 board
    [pomodoro-py32f002b.brd, pomodoro-py32f002b.sch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]
2024-08-08 added pwm to play melody
2024-08-09 Better method to enable and disable pwm
2024-08-12 Added code to enter deepsleep when button held for 3 seconds
2024-08-15 Reduce current on sleep by disabling outputs, updated hardware, rounded corners, changed leds from 0805 to 0603
    [BOM.xlsx, pomodoro-py32f002b.brd, pomodoro-py32f002b.sch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]
2024-09-01 Rename project and directories
    Rename project and directories to better reflect the fact that there are now 2 different hardware/firmware versions ( pic16f15354 and py32f002b )
    [APBD3224LSURKCGKC.stp, BOM.csv, BOM.xlsx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]

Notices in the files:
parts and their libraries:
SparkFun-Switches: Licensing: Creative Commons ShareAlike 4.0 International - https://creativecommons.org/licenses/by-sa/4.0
